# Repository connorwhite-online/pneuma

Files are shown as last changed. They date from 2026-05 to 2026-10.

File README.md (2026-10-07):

# Pneuma

**A standalone, screenless AI device with sight and sound — no phone, no app, no
memory of you except what it chooses to keep.**

Pneuma is firmware (and hardware) for a small wearable you can talk with, and —
*only when you ask* — let it see what you see. It carries its own cellular
connection, so it works on its own out in the world. You bring your own model (an
API key for a frontier provider). It is **ephemeral**: it stores no conversations,
no audio, no photos — nothing but one small, curated **memory file**.

> *Pneuma* (πνεῦμα) is Greek for **breath / spirit**. Each interaction is breath —
> it happens, then it's gone. The single memory file is the spirit that endures.

> Status: **early design / pre-implementation.** Architecture and research live
> in `docs/`; session firmware is a laptop-runnable scaffold, not device
> bring-up. Start with [`docs/ARCHITECTURE.md`](docs/ARCHITECTURE.md), then
> [`docs/RESEARCH.md`](docs/RESEARCH.md). An independent feasibility review of
> the standalone cellular spec is [`docs/FEASIBILITY.md`](docs/FEASIBILITY.md).

## What Pneuma is (and isn't)

- **Voice-first, screenless.** You speak; it speaks back. Wake word + button +
  haptics + audio cues — never a display.
- **Standalone.** Onboard **cellular (LTE Cat-1 bis)** — no phone, no companion
  app. Setup is a one-time web page the device hosts itself.
- **Vision on demand, not always-watching.** The camera powers on to grab a single
  frame *when you ask something visual*, then powers off. The opposite of the
  always-recording pendants that drew privacy backlash.
- **Bring your own LLM.** The brain is pluggable — OpenAI, Gemini, Grok, Claude.
  Your key is stored on the device, set once at setup.
- **Ephemeral + one memory file.** No history, no recordings. The only persistent
  state is a bounded (~KB), model-curated, user-resettable, portable memory file.

## How it works (one picture)

```
   ┌───────────────── PNEUMA DEVICE ──────────────────┐
   │  ┌───────────────┐   wake/power   ┌────────────┐  │   cellular (Cat-1 bis)
   │  │  WAKE ISLAND  │ ─────────────▶ │  SESSION   │  │  ──────────────────────▶  ┌──────────┐
   │  │  (always on,  │                │   BRAIN    │  │   audio + on-demand JPEG  │ PROVIDER │
   │  │   µA–mA)      │ ◀───────────── │ (Linux SoC │  │  ◀──────────────────────  │ your key │
   │  │ wake word/btn │   done/sleep   │ +modem+cam)│  │      audio reply          └──────────┘
   │  └───────────────┘                └─────┬──────┘  │
   │                              ┌──────────┴───────┐ │
   │                              │  memory file ~KB │ │  ← only persistent state
   │                              └──────────────────┘ │
   └───────────────────────────────────────────────────┘
```

A tiny always-on chip listens for the wake word; it powers up the Linux SoC +
cellular modem **only on demand** to answer, then shuts them off. That on-demand
burst (not continuous streaming) is what keeps it cool and the battery alive — the
thing the Humane Ai Pin got wrong. See [`docs/ARCHITECTURE.md`](docs/ARCHITECTURE.md).

## Repository layout

```
pneuma/
├── README.md
├── docs/
│   ├── ARCHITECTURE.md  ← system design, provider abstraction, ADRs
│   ├── FEASIBILITY.md   ← is the standalone spec actually buildable as v1?
│   ├── ENCLOSURE.md     ← aluminum body / thermal / waterproof / RF co-design
│   ├── MEMORY.md        ← the memory-file spec (the "spirit")
│   ├── PROVISIONING.md  ← one-time, app-less device setup
│   ├── PROTOCOL.md      ← internal wake-island ↔ Linux-SoC interface
│   └── RESEARCH.md       ← sourced research the design is built on
├── hardware/
│   └── BOM.md           ← bill of materials + interconnect map
└── firmware/            ← (planned) wake-island MCU + Linux session software
```

## Hardware core

A tiny always-on **wake-island MCU** (nRF52840 / Syntiant) + an on-demand **Linux
SoC** (Rockchip RV1106-class) + a **Quectel EG915U** LTE Cat-1 bis modem + a MIPI
camera, micro-speaker, mic, haptics, LED, and a ~500–1000 mAh LiPo. The
**aluminum unibody doubles as the heat exchanger** (the hot parts strap to it,
iPhone-17-Pro-style), it's **waterproof (IP68)** via a printed silicone gasket +
acoustic membranes + portless charging, and the cellular antenna sits behind a
non-metal RF window. Realistically small-puck / Ai-Pin-class — engineered to dodge
what killed the Ai Pin. Mechanical co-design: [`docs/ENCLOSURE.md`](docs/ENCLOSURE.md);
full BOM: [`hardware/BOM.md`](hardware/BOM.md); rationale in ADR-0001/0006/0007.

## License

[MIT](LICENSE) — fully open. Build it, fork it, sell it; just keep the notice.

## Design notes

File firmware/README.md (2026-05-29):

# Pneuma firmware

Two programs, matching the two-tier brain (see [../docs/ARCHITECTURE.md](../docs/ARCHITECTURE.md)).

## `session/` — the session brain (Rust, Linux SoC)

The on-demand brain: the **provider router** (Tier-1 realtime / Tier-2 composed),
the **interaction state machine** (Sleep → Connect → Capture → Converse → Forget),
and the bounded **memory file**. Hardware (modem, audio, camera, wake-island link)
sits behind traits in `session/src/hal`, with mock implementations so the whole
loop **builds and runs on your laptop today** — no hardware, no network, no keys.

```sh
cargo run  --manifest-path session/Cargo.toml    # run the mock interaction loop
cargo test --manifest-path session/Cargo.toml    # memory-file tests
```

Dependency-free for now (std only). Real drivers — an async runtime, a
WebSocket/WebRTC client to the provider, TLS, and vendor audio/camera libs — plug
in behind the existing traits. The OpenAI realtime driver stub (with the
implementation plan) is in `session/src/provider/openai.rs`.

Layout:
| Path | Job |
|---|-----|
| `src/state.rs` | the multi-turn interaction state machine |
| `src/provider/` | `Provider`/`Session` traits, `build()` router, Tier-1 (`mock`, `openai` stub) + Tier-2 `composed` (STT→LLM→TTS) |
| `src/hal/` | hardware traits (`AudioIn`+VAD, `Camera`, `Modem`, …) + mocks |
| `src/memory.rs` | the bounded memory file (load/save/compact + tests) |
| `src/tool.rs` | tool calling (MCP-style): `Tool` trait + registry + round-trip |
| `src/secure.rs` | `KeyStore` — resolves the API key from secure storage |
| `src/config.rs` | device config (provider/model/key handle) |

`provider::build(&config, &keystore)` is the router: it maps the provisioned
provider id to a Tier-1 or Tier-2 driver and pulls the key from the keystore. Both
tiers run on the laptop via mocks (`cargo run` shows a realtime conversation and a
composed query back to back).

## `wake-island/` — always-on co-processor (C, nRF52840 / nRF Connect SDK)

Wake-word + button, and power control of the session SoC. Builds against the
Nordic nRF Connect SDK (Zephyr) — not part of this repo's tooling. Scaffold only.

The interface between the two programs is specified in
[../docs/PROTOCOL.md](../docs/PROTOCOL.md).

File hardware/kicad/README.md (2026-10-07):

# Pneuma Rev A: KiCad projects (generated)

| Project | Board |
|---|---|
| `pneuma-main/` | PNM-MAIN: Luckfox Core1106-1408, nRF52840 (MDBT50Q), mics, MAX98357A, DRV2605L, camera FPC |
| `pneuma-pwr/`  | PNM-PWR: USB-C, BQ24074, LC709203F, EG800Q-NA, nano-SIM, FSUSB42, TXB0104 ×2, AT42QT1011 |

**Everything is generated from [`tools/design.py`](tools/design.py).** Edit the design there, then run
`tools/build.sh` (KiCad 10; `CQ_PY` must point to a Python with `cadquery shapely matplotlib` for the 3D check).
If you hand-edit the `.kicad_sch` or `.kicad_pcb` files, the next regeneration overwrites those edits. The exception is
**routing**: once routing starts in the KiCad GUI, stop running `gen_pcb.py` and use *Update PCB from Schematic*.
Footprint paths are set to the schematic symbol UUIDs to make that work.

- `lib/`: project symbols/footprints (Core1106 with carrier cutout, EG800Q-NA LGA-109 from the Quectel V1.1 drawings,
  RGB LED, pads) + 3D bodies
- `vendor/luckfox-core1106/`: Luckfox's KiCad symbol/footprint/STEP, pinout and schematic, unmodified
- `out/`: build output, **regenerated, mostly not versioned**. `build.sh` writes the board STEPs, schematic PDFs,
  ERC/DRC reports and the spreader DXF here; git keeps only the small readable ones (BOM CSVs, `layout-L.png`,
  `interference-L.json`). The STEP deliverables also go to the Desktop handoff folder.

Regeneration is deterministic in what matters: identical part placement, nets and coordinates every run
(`design.REV_DATE` freezes the title-block date; override with `PNEUMA_REV_DATE`). KiCad still assigns fresh
internal UUIDs and writes footprints in its own order, so the files are not byte-identical between runs.

Status: schematics pass ERC (0 errors); PCBs are placed with DRC 0 violations; **unrouted**. See [`../REV-A.md`](../REV-A.md).

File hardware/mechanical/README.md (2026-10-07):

# Enclosure K / electronics interface

Status: mechanical prototype, 2026-09-17. No fabricated or electrically validated custom PCB exists in this repo. `enclosure-k-interface.json` records CAD datums and provisional envelopes, not verified component footprints. Dimensions are millimeters. A blank mounting-hole field means undecided, not zero holes.

The current enclosure has two perimeter frames and two soft membranes. The rear rim is flush with its frame; the center recesses 0.65 mm. The internal upper spaces are opened up, and the USB wiring route connects to the main cavity. This supersedes the **mechanical concept** of a solid aluminum plateau/unibody described in older notes, but does not replace the outstanding thermal/RF analysis.

## Mounts we can establish now

Use frame-referenced rigid support for the main electronics and camera; use the TPU for cushioning and sealing. Avoid fastening alignment-critical optics into flexible membrane alone. The camera axis is 30 degrees toward the top. An angled mechanical carrier can hold the existing camera module and its FFC; an angled custom camera PCB is not required solely to set that angle.

Keep the newly opened upper volume available for a camera carrier, possible mic/LED board, speaker and cabling. It is not all free PCB area: speaker acoustics, camera lens projection, FFC bends, frame catches, antenna and thermal keepouts consume space. Final board shapes must be checked as populated assemblies, not bare rectangles.

Do not yet cut final screw bosses or hole patterns. Confirm board variants/outlines, height, mounting holes, connector entry and tool access first. An adjustable/removable carrier is preferable for early fit experiments. Choose screw size and boss geometry after measuring available wall and installation clearances.

## Board partition proposed for review

1. Main compute/power board or initial module carrier, referenced to the frame. Do not freeze a bare-RV1106 design before integration bring-up.
2. Camera module on an angled rigid carrier, native MIPI FFC back to compute.
3. Optional small mic/LED daughterboard near their ports. The IM69D130 is bottom-port: the PCB and seal need an aligned acoustic path. Do not connect two PDM clock drivers together; decide microphone ownership/routing explicitly.
4. Speaker held separately in a retained, sealed acoustic seat, with a removable wire connection. The 18 mm BOM speaker does not imply an 18 mm exterior opening, and the existing small outlet row has not been acoustically validated.
5. USB-C board/connector positively retained against cable insertion load, with the open interior wiring route. Choose the exact connector and power/data routing before mounting holes.
6. Touch electrode behind the thin touch area. Controller, electrode shape, ground keepout and sensitivity are not yet specified in the BOM.

The four enclosure pieces remain four pieces. Additional rigid electronic carriers, if selected, are internal assembly parts and need their own drawings.

## Decisions before schematic/placement freeze

- Existing development boards and intended cellular region/carrier. The BOM itself flags EG915U-EU as unsuitable for the proposed US use.
- Exact SC3336 module drawing and connector pin count/pinout; vendor module identity alone is insufficient for a footprint.
- Confirm whether two-way earbud microphone support is required. The repo's BM83 Tx-mode notes do not establish HFP Audio Gateway support.
- USB-C variant, input power requirement, charging/current budget, battery protection and temperature sensing. Do not treat the current mouth cutout as a verified connector fit.
- Antenna layout and thermal path for a perimeter-metal/soft-face enclosure. The old unibody heat-spreader assumption no longer applies.
- Main board thickness, stackup, connector heights and practical service/removal order.

## KiCad workflow

Create schematic sheets for power, wake/touch, compute, cellular, audio and interconnect only after sourcing the corresponding manufacturer reference designs and pinouts. Link each symbol/footprint to a checked part variant. Keep unknown values explicitly unresolved; do not substitute convenient footprints.

Export populated board STEP models from KiCad into enclosure coordinates. Check component bodies, solder joints, underside parts, connector mating and removal space, cable bends and screw access. Only then transfer actual board-hole coordinates into CAD and export new meshes.

Run ERC and DRC with a documented fab stackup, impedance constraints and reviewed exceptions. Passing these checks is not electrical validation. Bench-test power rails/current limiting, wake latency, audio, camera, modem bursts and thermal behavior before a fully integrated board spin. Fabrication outputs should be released only after the pending decisions and reviews are resolved.

## First bench milestones

Record exact board/firmware variants and wiring, then bring up each power domain separately on a suitable current-limited supply. Prove camera capture and audio locally, then add modem connectivity and the realtime workload. Measure peak current, wake-to-first-audio and sustained temperatures. Fit inert board/component dummies into the enclosure before installing a live battery. Log measured results and failures in the repo; no bench measurements have been performed as part of K.

For PLA enclosure fit, start with the latch coupon. The new geometry is a test iteration, not an SLM spring design or seal qualification.

## Manufacturer references checked during this update

- [Waveshare SC3336 Camera B](https://www.waveshare.com/wiki/SC3336_3MP_Camera_%28B%29): the B version changes the copper-plated fixing-hole provision. Confirm actual mechanical retention on the purchased module rather than assuming the A variant mounting details.
- [Infineon IM69D130 datasheet](https://www.infineon.com/assets/row/public/documents/24/49/infineon-im69d130-datasheet-en.pdf): package and acoustic-port guidance; use the manufacturer land pattern in the PCB design.
- [Microchip BM83 features](https://onlinedocs.microchip.com/oxy/GUID-414904F5-364E-4377-B959-9226AD29D6A9-en-US-8/GUID-90AB7782-7237-42CB-802D-B4DB2B9C5608.html): AT mode lists A2DP source or A2DP/HFP sink. That does not establish the HFP Audio Gateway role needed for an earbud microphone.
- [KiCad CLI documentation](https://docs.kicad.org/9.0/en/cli/cli.html): PCB STEP/GLB export for enclosure integration. Use documentation matching the installed version. KiCad was not installed on the workstation at this update; no ERC/DRC or native KiCad file validation has been run.

## Enclosure L (next): electronics interface for Rev A

Rev A boards are placed, and the enclosure grows **+10 mm** (a straight insert at y = −10; the camera end is unchanged).
[`enclosure-L-electronics.json`](enclosure-L-electronics.json) carries everything in these axes:
- board outlines, z-levels and M1.6 hole positions
- every part courtyard and side
- mic ports, LED, the USB-C mouth (z 6.46) and service access
- off-board envelopes: battery, FFC, speaker, LRA, camera

Requirements are listed in [`../REV-A.md`](../REV-A.md) §6. Populated STEPs come from `hardware/kicad/tools/build.sh`.

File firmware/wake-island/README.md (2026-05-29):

# Pneuma wake island (nRF52840)

Always-on co-processor firmware: wake-word + button detection and power control
of the Linux session SoC. C, on the **Nordic nRF Connect SDK (Zephyr)**.

```
west build -b nrf52840dk/nrf52840 firmware/wake-island
west flash
```
(Requires the nRF Connect SDK toolchain — not part of this repo's CI.)

## Layout
| File | Job |
|---|-----|
| `src/main.c` | the wake → power-up → hand-off → power-down loop |
| `src/wakeword.c` | always-on KWS on the PDM mic (TFLM/CMSIS-NN or Syntiant) |
| `src/button.c` | button gesture classification |
| `src/power.c` | `SOC_EN` control of the session tier |
| `src/uart_link.c` | control protocol to the SoC (see ../../docs/PROTOCOL.md) |

Status: **scaffold** — module bodies are TODO stubs.

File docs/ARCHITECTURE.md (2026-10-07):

# Pneuma — Architecture

Pneuma is a **standalone, screenless, voice-first AI device** with on-demand
vision and a pluggable ("bring your own") model. It carries its own cellular
connection — **no phone, no companion app** — and is **ephemeral**: it stores
nothing except one small, curated memory file.

This document is the synthesis of the research in [`RESEARCH.md`](RESEARCH.md).
Genuine forks are captured as **Architecture Decision Records (ADRs)** at the end.

Status: **design, pre-implementation.** This is the blueprint, built for the
*right* core rather than a throwaway prototype. An independent review of whether
this spec is a feasible *v1* (vs. a desk demo vs. a consumer product) is
[`FEASIBILITY.md`](FEASIBILITY.md).

> **Name & principle.** *Pneuma* (πνεῦμα) = breath / spirit. Each interaction is
> breath — it happens and is gone. The one persistent memory file is the spirit
> that endures. The device is otherwise stateless.

---

## 1. System overview

There is no phone in the loop. Three tiers, all on or beyond the device itself:

| Tier | What it is | Job | Power |
|---|---|-----|---|
| **Wake island** | Tiny always-on MCU (nRF52840 / Syntiant) | Wake word, button, sensors; powers the session tier up/down | µA–mA, always on |
| **Session brain** | Small Linux SoC (Rockchip RV1106-class) + **Cat-1 bis modem** + camera | Provider router, realtime session over cellular, on-demand photo, audio I/O | watts, **on-demand only** |
| **Provider (brain)** | User's chosen cloud model | Reasoning + (Tier 1) speech | remote, user's API key |

```
   ┌───────────────── PNEUMA DEVICE ──────────────────┐
   │                                                   │
   │  ┌───────────────┐   wake/power   ┌────────────┐  │      cellular (Cat-1 bis)
   │  │  WAKE ISLAND  │ ─────────────▶ │  SESSION   │  │  ─────────────────────────▶  ┌──────────┐
   │  │  (always on)  │                │   BRAIN    │  │     LC3/Opus audio + JPEG     │ PROVIDER │
   │  │ • wake word   │ ◀───────────── │ (Linux SoC │  │  ◀─────────────────────────   │ (your    │
   │  │ • button      │   done/sleep   │  + modem   │  │       audio reply             │  API key)│
   │  │ • mic monitor │                │  + camera) │  │                               └──────────┘
   │  └───────────────┘                └─────┬──────┘  │
   │                                         │         │
   │                              ┌──────────┴───────┐ │
   │                              │  memory file     │ │  ← the only persistent state
   │                              │  (bounded, ~KB)  │ │
   │                              └──────────────────┘ │
   └───────────────────────────────────────────────────┘
```

**Why a Linux SoC, not an MCU:** standalone realtime voice over cellular needs a
real WebRTC/TLS stack, hardware JPEG, OTA, and robust connection management.
Every shipping standalone-cellular voice device works this way (the Humane Ai Pin
used a phone-class Snapdragon). See ADR-0001.

**Why the wake island exists:** the Linux SoC + modem are power- and heat-hungry,
so they must be *off* almost always. A tiny always-on MCU listens for the wake
word and only powers the session tier up to answer, then cuts it. This on-demand
duty cycle is what keeps the device cool and the battery alive (see §6).

---

## 2. The interaction loop

```
   ┌──────────────────────────────────────────────────────────────────────┐
   │  SLEEP — session brain powered OFF; wake island listening (µA–mA)      │
   └───────────────┬────────────────────────────────────────────────────────┘
                   │ "Hey Pneuma"  (or button)  → wake island powers up brain
                   ▼
   ┌──────────────────────────────────────────────────────────────────────┐
   │  CONNECT — Linux SoC boots/resumes, modem attaches, loads memory file  │
   │  earcon (rising chime) + LED + haptic tap                              │
   └───────────────┬────────────────────────────────────────────────────────┘
                   │  (intent appears visual? "what am I looking at?")
                   ▼
   ┌──────────────────────────────────────────────────────────────────────┐
   │  CAPTURE (on-demand only) — power camera, grab ONE JPEG, then off      │
   │  visible/audible capture indicator                                     │
   └───────────────┬────────────────────────────────────────────────────────┘
                   ▼
   ┌──────────────────────────────────────────────────────────────────────┐
   │  CONVERSE — stream audio (+frame) to chosen provider over cellular;    │
   │  play voice reply; (optionally) update the memory file                 │
   └───────────────┬────────────────────────────────────────────────────────┘
                   │  silence / "thanks" / timeout
                   ▼
   ┌──────────────────────────────────────────────────────────────────────┐
   │  FORGET & SLEEP — drop all audio/frames/context, power modem + SoC     │
   │  down, return to wake island. Nothing kept but the memory file.        │
   └────────────────────────────────────────────────────────────────────────┘
```

The expensive tier lives only inside CONNECT→CONVERSE; the rest of the time the
device is asleep but listening. Camera is powered only inside CAPTURE.

---

## 3. The provider abstraction (the core of "bring your own LLM")

This runs **on the device** (in the Linux session brain), not in any app.
Providers expose their "brain" two ways; Pneuma implements both behind one
interface.

### Tier 1 — `RealtimeProvider` (native speech-to-speech)
One streaming socket: audio (and sometimes video) up, voice down. Lowest latency,
least local compute — ideal over cellular.
- **OpenAI** `gpt-realtime` — audio + image, WebRTC/WS.
- **Google Gemini Live** — audio + **native video (~1 fps)**, WebSocket.
- **xAI Grok Voice** — audio, WebSocket, **OpenAI-Realtime-compatible** (one driver → two providers).
- **AWS Nova Sonic** — audio, HTTP/2.

### Tier 2 — `ComposedProvider` (STT → text LLM → TTS)
Device orchestrates the pipeline (calling cloud STT/TTS APIs). **Required** for:
- **Anthropic Claude** — text/vision only, no native S2S.
- (Future) on-device/off-grid models, if the Linux SoC's NPU is ever used for a local fallback.

### Interface (illustrative)
```
Provider.startSession(opts) -> Session
Session:
  pushAudio(chunk)      // mic up
  pushImage(jpeg)       // on-demand frame up
  audioReply -> stream  // voice down
  transcript -> stream  // text, for memory updates / tools
  toolCalls  -> stream  // MCP
  endTurn(); close()
```
Adding a model = adding one driver + a stored key. The memory file is injected
into the session as context at start (see §5).

### Capability matrix
| Provider | Native voice | Vision | Auth |
|---|---|---|---|
| OpenAI `gpt-realtime` | ✅ | image | key + ephemeral token |
| Gemini Live | ✅ | ✅ video ~1fps | key + ephemeral token |
| xAI Grok | ✅ (OpenAI-compatible) | audio | key |
| AWS Nova Sonic | ✅ | audio | SigV4 |
| Anthropic Claude | ❌ → Tier 2 | image | key |

Glue: **MCP** for tools/routing. Keys are stored on-device (secure element /
encrypted flash), set once during provisioning (see [`PROVISIONING.md`](PROVISIONING.md)).

---

## 4. Hardware core

| Function | Part (indicative) | Notes |
|---|---|---|
| **Wake island** | Nordic **nRF52840** (or Syntiant **NDP120** for <1 mW KWS + beamforming) | always-on KWS (DS-CNN/TFLM), button, BLE for setup, powers the SoC |
| **Session SoC** | Rockchip **RV1106** (Cortex-A7 + ISP + ~0.5–1 TOPS NPU, tiny) | Linux; native MIPI camera ISP + HW JPEG; runs the provider router |
| **Cellular** | Quectel **EG915U** (LTE **Cat-1 bis**, single antenna, ~24×20×2.4 mm) | full-duplex, <100 ms; data-only (voice-over-data) |
| **Camera** | small MIPI-CSI sensor (via RV1106 ISP) | on-demand single JPEG; powered off otherwise |
| **Mic** | Infineon **IM69D130** (PDM) | monitored by wake island for KWS; routed to SoC in session |
| **Audio out** | **MAX98357A** (I2S) + 20 mm 8 Ω speaker; **+ Bluetooth A2DP** to earbuds | speaker fires toward face; earbuds = private/clear (ADR-0008) |
| **Haptics** | LRA + **DRV2605L** | state cues without a screen |
| **Indicator** | RGB LED | + earcons |
| **SIM** | **SGP.32 eSIM** or on-die **iSIM** | remote-provisionable, no UI needed |
| **Power** | LiPo ~500–1000 mAh + power-path PMIC + 100–470 µF bulk cap | LTE = steady ~0.8 A draw (no 2G spikes), so no supercap needed |
| **Thermal** | graphite/Cu heat spreader; outward radiating face; skin-side insulation | passive only (see §6) |
| **Storage** | SoC SPI-NAND/eMMC | holds OS + the memory file |

Full BOM + interconnect: [`../hardware/BOM.md`](../hardware/BOM.md).
Internal wake-island ↔ SoC interface: [`PROTOCOL.md`](PROTOCOL.md).

---

## 5. Ephemerality & the memory file

**Ephemeral by default.** No transcripts, no audio, no photos are retained. A
session's audio and any captured frame are streamed to the provider and dropped.
Nothing about *what you said or saw* persists.

**The memory file — the only persistent state.** A single bounded file (target a
few KB, hard cap) the model curates:
- **Content:** durable facts about the user (name, preferences, a handful of
  standing instructions) — *not* a conversation log.
- **Lifecycle:** read into the session as context at CONNECT; the model may
  propose updates during CONVERSE; on FORGET the device keeps only the updated
  memory file and discards everything else.
- **Bounded:** when near the cap, the model must *summarize/compress* rather than
  append — a rolling memory, so it never grows into a log.
- **On-device only:** never uploaded except as context to the user's *own* chosen
  model during a session. Stored in encrypted flash.
- **User-controlled:** viewable/editable during provisioning; **factory reset =
  forget me**; ideally **portable** (export/import to move your "self" to another
  Pneuma).

See ADR-0005.

---

## 6. Thermal & power (the make-or-break)

The Humane Ai Pin proved standalone-cellular AI is **thermally** hard: continuous
LTE streaming (~3 W modem) + an always-on app SoC is 2–6 W in a sealed body, which
throttled it. Skin-facing surfaces must stay **≤43 °C** (target ≤40–42 °C).

Pneuma's strategy is to *not generate the heat continuously*:
- **On-demand duty cycle** — the modem + SoC are off except during a session; the
  device bursts and sleeps, the regime that lets Apple Watch LTE and kids' GPS
  watches stay cool. (This is why the wake island exists.)
- **Aluminum body as the heat exchanger** (cf. iPhone 17 Pro): strap the two heat
  sources — the **modem PA** and the **SoC** — through TIM + graphite into the
  **aluminum unibody**, which radiates. On-demand bursts dump little energy into a
  large metal mass, so temperature barely rises. An *active* heat exchanger is
  **not feasible** at this scale (a few cm² shed only ~0.1–0.3 W/°C; no room/power
  for fans/pumps) — the body *is* the spreader. Radiate from the outward face;
  insulate the skin side (metal must stay ≤43 °C against skin).
- **Power** — LTE draws a steady ~0.7–0.8 A while connected (no 2 G micro-spikes),
  so a single LiPo + bulk cap + power-path PMIC suffices. Runtime ≈ hours of
  active talk; all-day on the on-demand model.

The aluminum body, the waterproof seal, and the antenna all interact (a metal body
is a Faraday cage, so the antenna needs a non-metal RF window) — designed together
in [`ENCLOSURE.md`](ENCLOSURE.md). See ADR-0006 and ADR-0007.

---

## 7. Privacy & trust posture

- **Standalone, no app, no Pneuma server.** Audio/photos go only to *your* chosen
  provider, over your own SIM.
- **Ephemeral.** Nothing to leak — no history, no recordings; only the small,
  on-device, user-resettable memory file.
- **On-demand capture** — camera powered only during an indicated CAPTURE; no
  ambient recording. This is the differentiator the always-on incumbents
  (Friend, Bee, Limitless) structurally lack.
- **Open + self-hostable-ish** — fully open firmware; the only cloud dependency is
  the model *you* chose and pay for.

---

## 8. Capabilities & power modes

Beyond conversation, the device's abilities are **tools** (§3, MCP-style) the model
invokes — adding a capability = adding a tool + any hardware it needs (real builds
register a tool only when its hardware/config is present). Each capability implies a
**power mode**:

| Mode | What | Power | Notes |
|---|---|---|---|
| Sleep / listen | wake-island only | µA–mA | always |
| On-demand Q&A | wake → cloud realtime burst → sleep | ~3 W, ~30–60 s | the core loop |
| Navigation | fetch route once → wake-island tracks GPS → SoC wakes per turn | ~0.3–0.7 W, sustained | needs a GNSS-capable modem + GNSS antenna; ~10–20 h |
| Media (Spotify/BT) | librespot stream → Bluetooth audio out | ~0.5–1 W, sustained | Premium; ~1 MB/min cellular data — prefer Wi-Fi; needs a BT-Classic/A2DP path |

- **Location/directions** — `get_location` + `directions` tools. On-demand ("how do
  I get to X?") is on-grain; live turn-by-turn is cheap *because the route is cached
  and tracking runs on the wake-island*, with the SoC waking only per turn.
- **Bluetooth audio out** (ADR-0008) — pairs AirPods/BT headphones for private,
  clear AI voice + music. A2DP source is mature on Linux (BlueZ); the requirement is
  a SoC/module with **BT-Classic/A2DP** support (the RV1106 IPC BSP is BLE-leaning),
  else a dedicated A2DP-source chip. Routed via a second `AudioOut` HAL impl.
- **Music over cellular is data-heavy** (~60 MB/h vs voice's ~20 MB/h) — fine on
  Wi-Fi, real money on a metered IoT SIM.
- **Projection (optional / experimental)** — this form factor *can* do on-demand,
  **glanceable 2D** projection (palm/surface) via a DLP Pico or laser-scanning engine
  behind a sealed optical window. The on-demand duty cycle keeps heat/battery in
  budget for brief (5–10 s) flashes — those walls only bite *sustained* bright use.
  Real limits: **daylight readability** (optics, not heat) and **packaging volume** vs.
  the battery. **Free-space 3D / holograms are not feasible** at any scale. Off the
  screenless thesis — a deliberate scope/cost tradeoff, not a default (Ai Pin proved
  it fits; its failure was UX, not feasibility).

---

## Architecture Decision Records

> **Decision history.** Earlier drafts assumed a phone-tethered, credential-free
> pendant (first on a single ESP32-S3, then a single nRF5340). Both were
> superseded when the **standalone, no-phone** requirement surfaced: with no phone
> to provide internet or hold keys, the device must carry cellular + a real SoC
> itself. The ADRs below reflect the standalone design.

### ADR-0001 — Standalone cellular on a small Linux SoC + always-on wake island

**Status:** Accepted. (Supersedes the phone-tethered ESP32-S3 and nRF5340 cores.)

**Decision.** Build a standalone device: a tiny **always-on MCU** (wake word +
power control) that boots a small **Linux SoC** (Rockchip RV1106-class) + a
**Cat-1 bis modem** (Quectel EG915U) + camera **on demand** for each session.

**Rationale.** No phone → the device needs its own internet radio and its own
compute. Realtime voice over cellular requires a Linux-class WebRTC/TLS/OTA stack
(unproven on bare MCUs; the Ai Pin used a Snapdragon). Cat-1 bis is the right
cellular tier (full-duplex, <100 ms, single antenna); LTE-M is too jittery for
live voice. The wake island keeps the power/heat-hungry tier off ~99% of the time.

**Consequences.** This is a tiny wearable Linux computer (Ai-Pin-class), not a
cheap flashable MCU — higher cost/complexity, accepted deliberately. Thermal is
the binding constraint (ADR-0006). Runtime is hours-of-talk / all-day-on-demand.

### ADR-0002 — Two-tier provider abstraction, device-resident

**Status:** Accepted (revised: now runs on the device, not a phone app).

The `RealtimeProvider` / `ComposedProvider` split (see §3) lives in the Linux
brain. It is the only way "bring your own LLM" covers both native-voice providers
and Claude/local. Keys are stored on-device, set once at provisioning.

### ADR-0003 — Audio output is a micro-speaker, not bone conduction

**Status:** Accepted. Bone conduction needs skull contact a pendant can't provide
(collarbone is its worst location); a micro-speaker is the only reliably
intelligible option. Caveat: weak outdoors, not private; optional BT-earbud
fallback.

### ADR-0004 — No companion app; one-time on-device web provisioning

**Status:** Accepted. (Replaces the earlier Flutter-app decision.)

There is no phone app. First-run configuration (API key, model choice, eSIM
profile, memory seed) is served by a web page the **device itself** hosts over a
temporary setup link (BLE/Wi-Fi SoftAP/USB), reachable from any browser, then
disabled. See [`PROVISIONING.md`](PROVISIONING.md).

### ADR-0005 — Ephemeral device with a single bounded memory file

**Status:** Accepted.

The device retains **no** conversation/audio/photo history. The only persistent
state is one bounded (~KB), model-curated, on-device, user-resettable, portable
memory file (see §5). This is the privacy foundation and the product's identity
(*pneuma* = breath vs. spirit).

### ADR-0006 — Thermal: passive spreading + on-demand duty-cycling, no active cooling

**Status:** Accepted.

An active heat exchanger isn't feasible at pendant scale. The device stays within
the ≤43 °C skin limit by **not generating heat continuously** (on-demand bursts,
via the wake island) plus **passive graphite/Cu spreading** to an outward
radiating face with skin-side insulation. Continuous streaming — the regime that
throttled the Ai Pin — is explicitly avoided.

### ADR-0007 — Aluminum unibody as heat spreader; sealed-USB-C waterproof; non-metal RF window

**Status:** Accepted.

**Decision.** Use an **aluminum unibody** as both structure and heat exchanger
(hot parts strapped to it via TIM + graphite); make the device **waterproof
(target IP68)** with a printed silicone gasket, acoustic membranes for mic/speaker,
and **sealed USB-C** charging+data (IP67 receptacle, gasket-wrapped); and place the
cellular antenna behind a **non-conductive RF window** in the body, isolated from
the metal.

**Rationale.** A metal body is the best passive spreader *and* a Faraday cage, so
the antenna must get a deliberate non-metal window; the outward face is contended
between radiator and antenna and is resolved in 3D (radiator + sides aluminum; RF
window at an edge, away from the body). USB-C is kept for data (flashing / dev /
recovery) and sealed IP67-style — the one waterproofing weak point, solved with a
gasketed receptacle.

**Consequences.** Bigger than a tiny pendant (small-puck/Ai-Pin class); the
enclosure becomes a real co-design of thermal + RF + sealing. Detailed in
[`ENCLOSURE.md`](ENCLOSURE.md).

### ADR-0008 — Bluetooth audio output (A2DP) is first-class

**Status:** Accepted.

**Decision.** Private, clear audio out via **Bluetooth A2DP** to earbuds/headphones
(AirPods or any BT sink) is **table-stakes**, alongside the speaker. Treat **BlueZ
A2DP-*source* support as a hard requirement** when selecting the production SoC /
Wi-Fi-BT module (Path A, ~$0 extra); fall back to a **dedicated A2DP-source BT-audio
chip fed by I2S** (Path B, ~$5–8) if the chosen SoC's BT stack can't. Adds a 2.4 GHz
BT antenna + a pairing flow; output routes through a second `AudioOut` HAL impl
(speaker vs BT, BT-when-connected).

**Rationale.** A bare micro-speaker is weak and non-private outdoors (ADR-0003);
earbuds make the assistant usable in public and double for music/calls. A2DP source
is mature on Linux (BlueZ) — the only real risk is the RV1106 IPC BSP being
BLE-leaning, hence the selection requirement. Optional **HFP** adds the earbud mic
for fully discreet two-way.

**Consequences.** Constrains the SoC/module choice (or adds a chip); ~100–200 ms
A2DP latency stacks on the cloud round-trip (use AAC for AirPods quality). Elevates
the BT-earbud "optional fallback" of ADR-0003 to a first-class output. **Resolved by
ADR-0009: Path B (dedicated BM83 chip).**

### ADR-0009 — SoC is RV1106 (G3) + a dedicated BM83 Bluetooth-audio chip

**Status:** Accepted. (Deep SoC pass — see [`RESEARCH.md`](RESEARCH.md) §8.)

**Decision.** Keep the **Rockchip RV1106 G3 (256 MB)** as the session SoC and add a
**Microchip BM83** (A2DP-*source* "AT" firmware, I²S + UART, ~$12) to own Bluetooth
audio. Do **not** step up to a larger SoC for Bluetooth's sake.

**Rationale.** The RV1106 already clears the two hard requirements that matter for
size: realtime audio (a single A7 + offloaded camera ISP/VPU is enough for Opus-over-
WebSocket) and the MIPI camera. Its *only* real gap is A2DP — its BlueZ stack is
broken/BLE-flavored — and a dedicated BM83 fixes that completely and cheaply, also
giving HFP (earbud mic) and hardware AAC (better AirPods quality than the Linux
libfdk-aac path). This honors the smallest/lowest-power priority while de-risking the
weak spot.

**Alternatives.** **RK3566** (quad-A55) is the documented one-chip fallback — mature
BlueZ A2DP + ISP + headroom, but ~1.2 W idle and bigger. **Qualcomm QCM2290** is the
"funded scale-up" ideal (dual ISP + **integrated LTE modem** + first-class Linux), but
production is NDA/SoM-gated. Disqualified: RK3308 (no usable camera), i.MX 8M Mini/7,
AM62x, STM32MP1, Allwinner T113 (missing ISP/encoder/MIPI).

**Consequences.** Several radios on the board (cellular + Wi-Fi/BLE + BM83 BT-audio +
GNSS) → 2.4 GHz antenna coordination is a real layout task. A 1-day hardware spike to
confirm A2DP-to-earbuds is still prudent, though the BM83 largely moots the risk.

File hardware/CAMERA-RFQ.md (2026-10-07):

# Camera module RFQ — Pneuma Rev A

Send this to camera module houses (Sincere, Hampo, CK Vision, Sinoseen, or any Shenzhen module
supplier). It is written so you can paste §2–§7 straight into an email. Background and the reasoning
behind the numbers are in [`REV-A.md`](REV-A.md) §7; coordinates are in
[`mechanical/enclosure-L-electronics.json`](mechanical/enclosure-L-electronics.json).

**Why this is blocking:** the PCB is finished and does not depend on which module you pick (the FFC
connector and its pinout are frozen). The *enclosure* cannot be modeled until the module's outline,
height and FFC exit are known.

---

## 1. Shortlist to ask about first

Any sensor below already has both a kernel driver and an **ISP tuning (IQ) file** in the Luckfox
RV1106 SDK, so it works without commissioning new tuning. In rough order of preference:

| Sensor | Format | Notes |
|---|---|---|
| **GC2053** | 1/2.9", 2 MP | the sensor in most small MIPI FPC modules — most likely to exist off-the-shelf in a compact build |
| **SC3336** | 1/2.8", 3 MP | Luckfox's own tested camera; the bench module uses it |
| **SC3338**, **SC2336**, **SC230AI**, **SC200AI** | 2–3 MP | all tuned in the SDK |
| SC4336, SC401AI, SC500AI, SC530AI, MIS2032, OS02H10, GC1084 | 2–5 MP | also tuned; only if the above can't be made short enough |

Full list in the SDK at `media/isp/release_camera_engine_rkaiq_rv1106_*/isp_iqfiles/`.

**Sensors without SDK tuning are a non-starter** unless the supplier provides an RV1106 IQ file.

## 2. What we need

A **fixed-focus MIPI CSI-2 camera module on an FPC/FFC tail**, for a battery-powered wearable that
takes occasional stills (not continuous video). Host SoC is a **Rockchip RV1106G3** (Luckfox
Core1106). Quantities: **3–10 samples now**, then 50–200 for a pilot build.

## 3. Mechanical (the hard constraint)

| Item | Requirement |
|---|---|
| **Module outline** | **≤ 12 × 12 mm** board |
| **Total height** | **≤ 6.0 mm** including the lens, measured from the module PCB's underside |
| Lens barrel | must not protrude more than the 6.0 mm total; no M12 holder |
| FFC tail | exits one edge, ≥ 25 mm usable length, 0.5 mm pitch, must fold 180° |
| Mounting | 2 holes or adhesive pad face; tell us what the module offers |
| Tolerance | we need a **2D drawing (PDF or DXF) and ideally a STEP model** before ordering |

The module sits tilted **30° from vertical**, which is why the footprint matters as much as the
height: a wider board swings its corners down into the SoC below.

**If you can offer a taller or wider module, tell us the exact numbers anyway** — we can trade
enclosure bump height against module size:

| Camera bump grows by | Largest module that still fits |
|---|---|
| **0 mm (preferred)** | **12 × 12 × 6 mm** |
| 1 mm | 16 × 16 × 6 mm |
| 2 mm | 16 × 16 × 7 mm |
| 4 mm | 16 × 16 × 9 mm |

## 4. Optical

| Item | Requirement |
|---|---|
| FOV | **90–110° diagonal** (a 150° fisheye is what makes most modules tall; we don't need it) |
| Aperture | F2.0–F2.4 is fine; we do not need F1.6–F1.9 if it costs height |
| Focus | fixed focus, hyperfocal from ~30 cm to infinity. No VCM/autofocus |
| IR filter | **IR-cut fitted** (daylight/indoor use, no night vision) |
| Resolution | 2 MP minimum; 3 MP preferred. Stills, ~1–5 fps, not 30 fps video |

## 5. Electrical

| Item | Requirement |
|---|---|
| Interface | **MIPI CSI-2, 2 data lanes + clock** |
| Supply | single **3.3 V** into the module; on-board LDOs for AVDD/DOVDD/DVDD |
| Control | I²C (SCCB), plus **RESET** and an external **MCLK** input |
| MCLK | tell us the required frequency (24 MHz preferred) and whether the module has its own oscillator |
| I²C address | tell us the 7-bit address and whether it is strappable |

## 6. Connector and pinout

Our board has a **20-pin 0.5 mm FFC connector wired to the Luckfox camera pinout**:

| Pin | Signal | Pin | Signal | Pin | Signal | Pin | Signal |
|---|---|---|---|---|---|---|---|
| 1 | GND | 6 | GND | 11 | CSI_D1N | 16 | RESET |
| 2 | MCLK | 7 | CSI_CLK P | 12 | GND | 17 | GND |
| 3 | GND | 8 | CSI_CLK N | 13 | I2C SCL | 18 | GND |
| 4 | CSI_D0P | 9 | GND | 14 | I2C SDA | 19 | +3.3 V |
| 5 | CSI_D0N | 10 | CSI_D1P | 15 | GND | 20 | +3.3 V |

**A 24-pin module is equally acceptable** — send us your standard pinout and we will match the board
to it. Please state:
- pin count and pitch
- **contact side: same-side (type A) or opposite-side (type B)** on the module end
- FFC stiffener location

## 7. Questions to answer with the quote

1. Part number, and the **2D drawing + STEP** for the exact build
2. Module outline and **total height including lens** (mm)
3. Sensor, lens EFL, FOV, F-number, IR-cut yes/no
4. FFC pin count, pitch, contact side, tail length
5. MCLK requirement and I²C address
6. **Do you supply an RV1106/RK ISP tuning (IQ) file for this sensor+lens pair, or should we use the Luckfox SDK's?**
7. MOQ, unit price at 10 / 50 / 200, lead time for samples
8. Whether you can supply **one sample with a 20-pin Luckfox-pinout tail** for immediate bring-up

## 8. What we do while waiting

Bench work uses the **Waveshare/Luckfox SC3336 3MP Camera (B)** ($9), which matches J4's pinout
exactly. That proves the driver, ISP and capture path; only the mechanical fit depends on this RFQ.

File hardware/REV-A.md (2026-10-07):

# Pneuma Rev A: board and BOM freeze (bench, then enclosure L)

Status, 2026-09-19. **Frozen:** architecture, part selection, schematics, board outlines, component placement,
inter-board pinout and the enclosure interface. **Not done:** copper routing, fab outputs and any electrical
validation. The PCBs are *placed, not routed*. Nothing here has been built or powered.

| Artifact | Where |
|---|---|
| Single source of truth (every part, pin and net) | [`kicad/tools/design.py`](kicad/tools/design.py) |
| KiCad 10 projects (schematic + placed PCB) | [`kicad/pneuma-main/`](kicad/pneuma-main), [`kicad/pneuma-pwr/`](kicad/pneuma-pwr) |
| Board BOMs (grouped, with MPNs) | [`kicad/out/pneuma-main-bom.csv`](kicad/out/pneuma-main-bom.csv), [`kicad/out/pneuma-pwr-bom.csv`](kicad/out/pneuma-pwr-bom.csv) |
| Populated board STEPs (KiCad export) | `kicad/out/pneuma-main.step`, `kicad/out/pneuma-pwr.step` |
| Enclosure-L interface (all coordinates, z-levels, envelopes) | [`mechanical/enclosure-L-electronics.json`](mechanical/enclosure-L-electronics.json) |
| Layout plan + side view | [`kicad/out/layout-L.png`](kicad/out/layout-L.png) |
| Thermal estimate (why there's no spreader) | [`kicad/tools/thermal_estimate.py`](kicad/tools/thermal_estimate.py) |
| Regenerate everything | `hardware/kicad/tools/build.sh` |
| Camera module RFQ (blocking enclosure L) | [`CAMERA-RFQ.md`](CAMERA-RFQ.md) |

Checks run on the generated files with KiCad 10.0.6 `kicad-cli`:
- **ERC:** 0 errors on both boards.
- **DRC:** 0 violations apart from unrouted nets.
- **3D:** a solid-intersection check of boards, battery, FFC, speaker, LRA and camera envelopes found 0 interferences.

None of these checks is electrical validation.

---

## 1. What changed from the old BOM, and why

| Old | Rev A | Reason |
|---|---|---|
| Quectel **EG915U-EU** | **EG800Q-NA** (Cat-1 bis, B2/4/5/12/13/66, LGA-109 15.8×17.7×2.4) | EG915U-EU has no US bands. EG800Q-NA covers AT&T/Verizon LTE and T-Mobile except B71. It is stocked at JLCPCB (C41406928). |
| Bare RV1106G3 custom SoC | **Luckfox Core1106-1408** SoM (RV1106G3, 256 MB, 8 GB eMMC, WiFi6/BT5.2) | Your choice: the SoC, DDR, eMMC, PMIC and radio are Luckfox-validated, so first-spin risk drops. |
| Microchip BM83 | **Removed** (Core1106 BT5.2 for A2DP, validated on the bench first) | 32×15 mm doesn't fit. The BM83 AT firmware also has no HFP-AG role. |
| SC3336 3MP Camera (B) | **Connector/pinout frozen (Luckfox 20P); the module itself is NOT chosen** — see §7 | The (B) is 25×24 mm with a 23.95 mm M12 lens stack and can't fit even tilted. The board doesn't care which module you use; the enclosure bump does. |
| PKCell LP803860 2000 mAh | **LP702040, 500 mAh / 1.85 Wh, 7.0×20×40 mm** with PCM + wires | Volume. See §4. (The 550 mAh version of the same cell is 41 mm long and needs 1 mm more bay.) |
| PUI AS01808MR-R 18 mm speaker | **PUI AS01508MR-LWC40 class, 15 mm** | 18 mm collides with the camera over the Core. |
| USB-C GCT USB4500 (IP67) | **GCT USB4105-GF-A** | K's port isn't sealed yet. The IP67 part returns with the seal design. |
| BQ24074 on VSYS for everything | BQ24074, but **modem on VBAT** | BQ24074 OUT regulates to **4.4 V**, above the EG800Q's 4.3 V maximum (TI datasheet, device comparison table). |
| Aluminum perimeter frames + TPU membranes (K) | **Two-piece silicone/TPU shell, no metal**, plus a rigid internal carrier | A metal ring around the whole device was the biggest unsolved LTE-antenna problem. Soft skin also feels cooler at the same temperature. |
| Aluminum unibody as heat sink + graphite | **PCB copper does the spreading; two off-the-shelf silicone gap pads** carry board→shell | Measured first: a 60 s session lifts the device ~2.3 K, and the 43 °C ceiling is set by skin area (~3.3 W continuous) regardless of internals. A vapor chamber doesn't fit and only spreads; a copper-foil + rigid-post stack can't hold pressure against a soft shell. |

## 2. Architecture (two boards + FFC)

```
 camera end ─────────────────────────────────────────────────────────────── USB end
 PNM-MAIN (45×44 mm pebble cap, 4L 0.8 mm)   battery bay   PNM-PWR (41×39 mm + USB tongue)
  top:  Core1106-1408 (RV1106G3 + WiFi/BT)    ≤7×20×40      top: EG800Q-NA, nano-SIM, USB-C,
        status LED, speaker/LRA pads,         LiPo           FFC, JST-GH battery, TVS, SIM ESD
        10 test pads                                          btm: BQ24074, LC709203F gauge,
  btm:  nRF52840 (MDBT50Q), 2 mics, amp,                           FSUSB42 USB mux, 2× TXB0104,
        DRV2605L, load switch, camera FPC,                         AT42QT1011 touch, U.FL, 12 TPs
        FFC, Tag-Connect SWD
        └──────── 30-way 0.5 mm FFC, straight-through, runs UNDER the battery ────────┘
```

**Power.** USB-C → BQ24074 (1.21 A input limit, 270 mA charge) → VSYS (3.5–4.4 V).
- VSYS feeds the Core1106 (through the TPS22917 load switch; the module's own PMIC accepts 2.7–5.5 V), the nRF VDDH, the MAX98357A and the DRV2605L.
- The modem runs from VBAT with 2×47 µF, a TVS and an HF cap array, as Quectel recommends.
- The nRF52840 runs in high-voltage mode, and its REG0 output is the always-on 3.3 V rail (+3V3_AON, ≤25 mA).

**Control.** The nRF52840 is the always-on wake island. It owns:
- the PDM wake mic
- SoC power (enable and reset) and wake/IRQ lines
- the modem's PWRKEY, RESET, STATUS, RI and DTR
- the I²C bus to the haptic driver and fuel gauge
- the USB mux select
- the touch input, charge status and RGB LED

**Data.**
- SoC ↔ modem: USB 2.0 through the FSUSB42 mux (SEL=1). The default, SEL=0, routes the SoC's USB to USB-C for flashing and ADB. There's also a 4-wire UART5 link through a level shifter.
- SoC ↔ nRF: UART3.
- Camera: MIPI-CSI, 2 lanes.
- Audio out: I²S to the MAX98357A.
- Audio in: an analog MEMS mic into the RV1106 codec for session audio.

**Inter-board FFC (30P, pin n ↔ pin n):**

| Pin | Net | Pin | Net | Pin | Net |
|---|---|---|---|---|---|
| 1 | GND | 11 | MDM_RXD_3V3 | 21 | MDM_STATUS |
| 2–5 | VSYS (4×0.5 A) | 12 | MDM_TXD_3V3 | 22 | MDM_RI |
| 6, 7 | GND | 13 | MDM_RTS_3V3 | 23 | MDM_DTR |
| 8 | USB_SOC_DP | 14 | MDM_CTS_3V3 | 24 | USB_SEL |
| 9 | USB_SOC_DN | 15 | GND | 25 | CHG_N |
| 10 | GND | 16 | +3V3_AON | 26 | VBUS_DET_3V3 |
| | | 17, 18 | I2C_SCL / SDA | 27 | TOUCH_OUT |
| | | 19, 20 | MDM_PWRKEY / RESET | 28 | +3V3_SOC |
| | | | | 29, 30 | GND |

### Design rules that firmware and bring-up must respect
1. **Program UICR.REGOUT0 = 3.3 V** on the nRF's first boot; the factory default is 1.8 V. Configure P0.18 as PSELRESET.
2. **Leave Core1106 pins 60/61/62/67 and 63/64/68/69 unused.** On the Wi-Fi variant they are tied through 1 kΩ to WL_EN/HOST_WAKE or carry the BT UART (Luckfox schematic).
3. **No back-powering.** While SOC_EN is low, the nRF must hold every SoC-facing line low or Hi-Z. The modem-UART translator's VCCB is +3V3_SOC, so it switches off along with the SoC.
4. **Charge termination.** The modem loads VBAT directly, which can block termination while charging. Keep the modem in DRX/sleep while on USB, or accept timer-based termination.
5. **Default USB mode.** The SoC's USB comes up routed to USB-C. Host mode toward the modem needs a device-tree role switch (usb-role-switch).

## 3. What stretches the boards

Courtyard areas from the placed PCBs:

| Board (area) | Biggest items | Why it's fixed |
|---|---|---|
| **PNM-MAIN** (1651 mm²) | Core1106 32×32 (**1023 mm², 62%**); nRF module 16.6×11.6 (192); FFC 21.2×8 (169); camera FPC 16.2×8 (129) | The Core's underside parts force a **24.2×21.3 mm cutout** through the carrier, so ~515 mm² of the *bottom* side under it is unusable. Everything else has to crowd into an L-shaped strip 6–12 mm wide around it. |
| **PNM-PWR** (1185 mm²) | EG800Q-NA 18.8×16.9 (**317**); nano-SIM 14.7×15.5 (**228**); FFC 21.2×8 (169); USB-C 10.7×9 (97); JST-GH 7×6.5 (46) | The modem alone is taller (17.7 mm) than K's whole lower bay (~16 mm). The SIM holder is nearly as big as the modem. The FFC connector (2.0 mm tall) can't go underneath, where there's only 1.5 mm of clearance. |

Length budget along the device (L interior ≈ 94 mm):
- main board: 45 mm (Core 30 mm plus a 6 mm nRF/FFC strip and an 8 mm top cap)
- battery: 21 mm
- power board: 26 mm (modem row 17 mm, FFC/battery-connector row 8 mm)
- USB tongue: in the channel

**Shrinking the boards, most to least effective:**
1. **Bare RV1106G3 instead of the Core1106** (Rev B): recovers the ~515 mm² cutout and the module's 1.6 mm PCB. It's the only change that gets back toward 1000+ mAh. The cost is the risk you chose to defer.
2. **MFF2 eSIM (5×6 mm) instead of the nano-SIM**: saves ~220 mm² on PNM-PWR. You'd lose SIM swapping on the bench, and the eUICC needs provisioning.
3. **Solder the battery leads instead of the JST-GH**: saves ~46 mm².
4. **Custom low-profile FPC connectors** (≤1.0 mm, e.g. Hirose FH19C class): would let the FFC move to the underside. That needs new footprints; there are no stock KiCad ones.

## 4. What keeping K's exact size would have cost

K interior is ~84 mm long; L adds 10 mm. At K length, one of these has to give:
- **Keep this layout:** the battery bay shrinks from 21 to ~11 mm, about **250–300 mAh**, roughly half of L.
- **Or keep ~450–500 mAh** by taking items 2–4 above together:
  - an eSIM instead of the removable nano-SIM
  - battery leads soldered directly
  - no modem keep-out margin, which makes rework harder
  - low-profile connectors that need custom footprints

  That's still ~20% less battery than L.

What L gives you: ~550–600 mAh (2.0–2.2 Wh), which works out to about 40 min of continuous LTE talk at ~3 W, or ~30 h of registered-idle standby at ~18 mA. These are estimates to bench-measure, not results. Keep in mind that the old "2000 mAh / ~10 h" figure never fit K either.

## 5. Bench plan

### Phase 0: dev kits (buy now, no custom boards)
Each item matches a Rev A part so code and wiring carry over.

| Item | Why | ~$ |
|---|---|---|
| Luckfox **Pico Ultra W** (RV1106G3 + WiFi6/BT5.2) | Same SoC and radio family as Core1106-1408. Answers the A2DP-on-BT5.2 question. | 30 |
| Luckfox **SC3336 3MP Camera (B)** | Same Luckfox 20P pinout as J4 on PNM-MAIN | 9 |
| **Quectel EG800 EVB, NA variant** (DigiKey), or skip and bring up on a PNM-PWR | Same modem and AT set as Rev A. The Electromaker listing is the EU variant. | EVB |
| Adafruit **Feather nRF52840 Express** (MDBT50Q-1MV2) | Same module as U3. Wake word, UART to SoC, power sequencing. | 25 |
| MAX98357A (Adafruit 3006), DRV2605L (Adafruit 2305) + Vybronics **VG1040003D**, PUI **AS01508MR-LWC40** | Audio and haptics chain as on the board | ~25 |
| BQ24074 (Adafruit 4755) + LC709203F gauge breakout + a 500–600 mAh 1S cell | Power path and fuel-gauge firmware | ~25 |
| US IoT nano-SIM (Hologram or Soracom plan-US), U.FL LTE antenna (Molex 2091420180) + pigtail | Real network attach on US bands | ~15 |
| Tag-Connect TC2030-CTX-NL + SWD probe | Same programming path as Rev A | ~40 |

**Numbers Phase 0 must produce before fab:**
- wake-to-first-audio, with the modem in registered-idle vs. powered off
- idle current (target < 20 mA)
- modem TX peak current and VBAT droop
- whether A2DP to earbuds works on BT5.2
- whether RV1106 runs app + camera + modem at once
- SoC-surface temperature over a 60 s session

### Phase 1: Rev A boards (after routing)
- **Fab:** 4-layer, 0.8 mm, ENIG, 0.1/0.1 mm rules, controlled impedance for USB (90 Ω), MIPI (100 Ω) and a 50 Ω RF feed. JLC assembles everything except the Core1106, which is a hand-solderable stamp-hole module. The EG800Q LGA must be machine-placed.
- **Bring-up order:**
  1. VBUS/VSYS on a current-limited supply
  2. nRF (SWD, UICR, +3V3_AON)
  3. SoC_EN → Core boot on USB-C (ADB)
  4. camera
  5. audio
  6. modem PWRKEY → AT over USB (USB_SEL=1) → attach
  7. touch
  8. charge
- **Fit:** check the PLA fit of the L prototype with dummy boards (the exported STEPs) before installing a live battery.

## 6. Requirements for enclosure L

Everything is in [`mechanical/enclosure-L-electronics.json`](mechanical/enclosure-L-electronics.json), in K's axes.

0. **Construction:**
   - Two soft shells, front (+z, outward: camera, touch, LED) and rear (skin side, kept insulating), in silicone or TPU, 0.8–1.2 mm walls. **No aluminum frame.**
   - A rigid internal carrier (PC, nylon or PA12) locates the boards, battery, speaker, LRA and camera, and takes the M1.6 screws. The shells seal and cushion around it.
1. **Length +10 mm:** insert a straight section at y = −10. The camera end is unchanged; everything at the USB end moves −10 mm, so the interior spans y −59…+47.6.
2. **Board supports:**
   - PNM-MAIN underside at **z 4.7** (top 5.5). PNM-PWR underside at **z 4.0** (top 4.8).
   - Rear floor stays at z 2.45. The lowest parts sit at z 2.56 (main-board FFC connector) and z 2.66 (power board).
   - M1.6 holes: main (−11.8, 41.5) and (12.8, 41.35); power (15.6, −21.6) and (−19.8, −22.6).
   - Use a rigid frame-referenced carrier, not screws into TPU (same guidance as K).
3. **Headroom over the Core:** extend the camera-bump pocket down to y ≈ 2.5 so everything stacked on the Core fits:
   - speaker Ø15×3.5 at **(−8, 12.4)**, top z 12.1 — nudged +2.2 mm so it clears the touch pad
   - LRA Ø10×4 at **(−10.5, 30.5)**, top z 12.6 (moved off the Core1106 Wi-Fi/BT chip antenna at x 10.5–13.7, y 10.5–13.5)
   - SoC thermal post
   - camera envelope: 11×11×6 mm on the 30° axis at K's aperture (0, 26, 16.8)
4. **Battery pocket (LP702040, 7.0×20×40 mm):** x −20.4…19.6, y −19.3…1.3, z 2.85…9.85, with the FFC (16.5 mm wide) underneath at z 2.5–2.8. The FFC needs an S-bend clearance at PNM-PWR J5: y −21.4…−19.3, z up to 6.8.
5. **USB-C:** mouth at y −58.8, centre z **6.46** (K had 6.1). The exterior wall around the port must be thin or counterbored so a standard plug (overmold ~12.4×6.5) seats fully.
6. **Openings in the front skin:**
   - mic ports above MK1 (−15.9, 17.3) and MK2 (−15.9, 22.1), with gaskets
   - speaker vents over (−8, 10.2)
   - LED light pipe at (0.7, 44.3)
   - **touch pad: 24 × 16 mm electrode on the front membrane's inner face, x −12…12, y −12…4** — i.e. ~10 mm below the camera bump's lower edge. Spring contact to **PNM-MAIN TP11** at (11.0, 4.6); the AT42QT1011 front-end (U6) is on the main board beside the nRF, so the electrode run is short and TOUCH_OUT no longer crosses the FFC
7. **RF:**
   - No copper or metal in the keep-out at x 9–23.5, y 2–16. That covers the nRF chip antenna and the Core1106 Wi-Fi/BT antenna.
   - **LTE antenna pockets** in the soft USB-end wall on either side of the USB channel: x −21…−7.5 and 7.5…18, y −50.5…−47, z 3–10. This only works because there's no metal frame. The FPC antenna part is still to be picked.
8. **Thermal — no spreader, no cutting.** Numbers from [`kicad/tools/thermal_estimate.py`](kicad/tools/thermal_estimate.py):

   | | |
   |---|---|
   | Skin area 186 cm², to-air ≈ **5.4 K/W** | **43 °C skin is reached at ~3.3 W continuous** — that ceiling is set by surface area, not by anything inside |
   | Device heat capacity ≈ 72 J/K, time constant ≈ 6 min | **A 60 s session at 3 W lifts the whole device ~2.3 K** |
   | Modem → shell across a bare 1.5 mm air gap | +8 K at 60 s, but **+36 K at 10 min** |
   | Same step with **one silicone gap pad** | +0.5 K |

   So the burst interaction needs no thermal hardware at all, and the gap pads exist for sustained modes.
   - **The PCB is the spreader.** 4-layer copper goes isothermal in milliseconds. Routing must put a thermal via field under the EG800Q-NA ground pads into both inner planes, stitch the Core1106 GND stamp pads in, and not neck inner copper around the modem. Zero parts, zero assembly.
   - **Two off-the-shelf silicone gap pads**, ≥3 W/mK, 3 mm, pre-cut squares: one on the modem lid (x −15…−3, y −42.5…−31), one on the Core1106 top between the LRA and camera (x −5…2, y 31…37). Compressible, so they absorb the tolerance of a soft shell — which a rigid post cannot. Non-conductive, so unlike copper they impose no antenna or touch keep-outs.
   - **Firmware duty limiting is the real control**, because the ceiling is skin area.
   - **If the bench disagrees:** cast the front shell in thermally conductive silicone (k 1–3, no extra parts, just a different material at mould time), or peel-and-stick pre-cut graphite pads inside the front shell.
   - **Rejected:** the ATS-VC-042 vapor chamber (100 × 40 × 3 mm, 18 g, rated 124 W) — longer than the cavity, no 3 mm layer spare, and it only spreads. Also rejected: the copper-foil + shim-post + putty stack I specced first. It was fiddly to assemble and depended on a rigid post holding pressure against a silicone wall.

## 7. Open items (not frozen, need a decision or a measurement)
- **Routing** both boards: impedance-controlled USB, MIPI and RF; power pours; via-in-pad under the LGA. This is the next KiCad task.
- **LTE antenna part:** pick an FPC antenna (698–2700 MHz, MHF1 pigtail) that fits the USB-end pockets (§6.7), then tune the pi-match. With the metal frame gone this is ordinary RF work. The bench uses an external antenna on the U.FL.
- **CAMERA MODULE — not chosen, and it blocks enclosure L.** The PCB is unaffected (J4's 20P pinout is frozen and every option below uses it), but the bump cannot be modeled until this is settled:
  - **The choice of sensor is much wider than Luckfox's "supported" page suggests.** Their RV1106 SDK ships ISP tuning (IQ) files for `sc3336, sc3338, sc2336, sc230ai, sc231hai, sc200ai, sc4336, sc401ai, sc500ai, sc501ai, sc530ai, sc301iot, gc2053, gc1084, gc2093, gc4023, gc4653, mis2032, mis5001, os02h10, os02k10, os04a10, imx415, sc031gs`, and the SDK kernel carries ~150 sensor drivers. **GC2053 is tuned and supported**, which matters because it's the sensor in most small MIPI FPC modules sold for RK/RV platforms.
  - **Height comes from the lens, not the sensor.** The Waveshare (A)/(B) are ~22 mm tall because of an M12 holder; Hampo's GC2053 module is 18.6 mm because of a 150° F1.9 lens. A 90–110° board lens on the same sensor is far shorter.
  - **What the mechanics actually allow** (measured by sweeping solid clashes, not estimated). The limit is *not* the bump — it's the Core1106 top at z 8.42, the speaker and the LRA sitting right under the module:

    | Bump growth | Largest module that clears |
    |---|---|
    | none | **12 × 12 × 6 mm** (11 × 11 × 6 with the LRA where it is now) |
    | +1 mm | 16 × 16 × 6 mm |
    | +2 mm | 16 × 16 × 7 mm |
    | +3 mm | 16 × 16 × 8 mm |
    | +4 mm | 16 × 16 × 9 mm |

    Anything past 12 × 12 also needs the LRA moved off the camera footprint.
  - **Option A — ship the SC3336 (B) ($9, verified):** needs a Ø14 × 22 mm angled barrel housing. No sourcing, but it's a periscope, not a wearable bump.
  - **Option B — board-lens FPC module (recommended):** RFQ ready to send in [`CAMERA-RFQ.md`](CAMERA-RFQ.md). any sensor from the tuned list above, ≤12 × 12 × 6 mm, 90–110° FOV. Module houses (Sincere, Hampo, CK Vision, Sinoseen) quote at MOQ 3–10. Send them the envelope, the FOV and the pinout; ask for the shortest board lens they stock.
  - **Option C — drop the 30° tilt:** shortens the bump, changes the framing K was designed around.
  - **Connector caveat:** J4 is 20P on the Luckfox pinout, which is what the bench (B) uses. Many compact modules are **24P**. Regenerating J4 for a 24P module is a small change to `design.py`, but the module's drawing and pinout have to come first.
- **Thermal numbers:** skin temperature over a 60 s and a 10 min session, with and without the copper spreader (Phase 0 mock-up: copper tape inside a printed TPU shell).
- **Speaker acoustics** (front volume, vents) — note the vents now sit just above the touch pad.
- **Sustained-mode thermals:** 10 min at 3 W is where the gap pads and duty limiting earn their place. Measure it in Phase 0 before deciding whether the front shell needs conductive silicone.
- **Touch sensitivity:** the battery pouch is ~1–2 mm behind the pad's lower half and the speaker sits just above it; both reduce sensitivity. Tune C25 (Cs) against the final electrode, and consider a foam spacer to hold the electrode off the metal.
- **RF pi-match** R14/C13/C14 values, tuned on the real antenna.
- **Passive specs** in the CSVs are value + footprint only. Use X5R/X7R ≥6.3 V (≥10 V on VBUS/VSYS bulk) and 1% resistors. Pick LCSC part numbers at order time.

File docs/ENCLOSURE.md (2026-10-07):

# Pneuma — Enclosure, Thermal & RF (mechanical design)

> **Current prototype:** [Enclosure K mechanical interface](../hardware/mechanical/README.md) describes the perimeter-frame/soft-membrane design. The unibody and stacked-board assumptions below are historical and require reconciliation before PCB fabrication.

The body is not just a shell — it is the **heat exchanger**, the **waterproof
barrier**, and part of the **antenna system** all at once. These three jobs
interact, so they're designed together here. Rationale tie-ins:
[`ARCHITECTURE.md`](ARCHITECTURE.md) §6 + ADR-0006/0007;
[`RESEARCH.md`](RESEARCH.md) §thermal.

Status: **design.** Enclosure is intended to be iterated (3D-printed first).

---

## 1. Aluminum body as the heat exchanger

Approach (cf. iPhone 17 Pro: metal mass + heat spreader): conduct heat from the
hot parts into the aluminum unibody and let the whole body radiate.

**What gets hot (strap these, ignore the rest):**
1. **Cellular modem PA during TX** — ~0.7–0.8 A ≈ ~3 W while connected. #1 source.
2. **Linux SoC** (A7 + NPU during a session). #2.
3. Camera (brief), battery (while charging).

**Thermal path:** modem PA + SoC → thermal interface material (TIM/pad) →
graphite spreader → **aluminum unibody**.

**Why it works here:** on-demand bursts (30–60 s) dump little energy into a
comparatively large metal mass → temperature barely rises; the body soaks and
re-radiates afterward. *Continuous* operation overruns thermal mass (what cooked
the Ai Pin); Pneuma doesn't do that (ADR-0006).

**Skin-side caveat:** the body also contacts the chest, and metal feels hot faster
than plastic (effusivity). The **≤43 °C** limit applies to the skin-facing metal.
So **radiate from the outward face; insulate / stand off the skin side** (low-
conductivity layer between hot side and skin). The thin-slab + plateau layout (§4)
does this structurally: hot parts live in the **outward aluminum plateau**, the
skin side is the **cool battery slab**. Short bursts likely stay well under the
limit; design for the long-session case anyway.

---

## 2. Waterproofing (target IP68)

A printed **silicone gasket** compressed between **two aluminum shells** seals the
body (target IP68). Anodize the aluminum (scratch/corrosion); the silicone can
extend into an external **bumper** for drop protection. Four things sealing
touches, designed back in:

- **Acoustic membranes** over the mic and speaker (Gore/Saati) — pass sound, block
  water. One also serves as the **pressure-equalization vent** a sealed device
  needs.
- **USB-C charging + data** (chosen over portless Qi/pogo): Qi won't pass the
  aluminum body, and a data port is worth keeping — flashing the Linux SoC,
  dev/debug, recovery from a bad OTA, and a non-cellular firmware-update path. The
  cost is that the port is the one genuine waterproofing weak point; solve it the
  way IP68 phones do — a **gasketed/waterproof USB-C receptacle** sealed to the
  PCB so water can enter the cavity, drain, and never reach the interior, with the
  silicone gasket **wrapping the opening**.
- **RF window = the gasket** — a real **slot/aperture in the aluminum**, filled by
  the RF-transparent silicone gasket, both seals and lets the antenna radiate
  through (§3).
- **LED indicator window** — an *optical* gap: a clear polycarbonate insert or
  **translucent silicone** over the LED (so the gasket glows), or a sealed
  light-pipe. Sealed either way.

**Whole-body heat — a thermal-break caveat:** silicone between the two aluminum
shells is a *thermal break*, so heat strapped to the plateau shell won't flow into
the other shell on its own. Either **accept it** (with on-demand bursts the
plateau shell has ample surface — start here) or **bridge it** with a small
metal-to-metal contact / thermal strap across the gasket at one spot (more sealing
complexity). Decide from bench data.

(Conduction-only cooling is unaffected by sealing — there's no airflow at this
scale regardless, so waterproofing doesn't hurt the thermal design.)

---

## 3. Antenna vs. aluminum body — the central RF tension

**A sealed aluminum body is a Faraday cage; the antenna cannot live inside the
metal.** The fix: a real **slot/aperture in the aluminum**, filled by the
RF-transparent **silicone gasket itself** (one part, two jobs — seal + RF window),
with the FPC antenna behind it. (Like the plastic antenna breaks in phone metal
frames.)

**Tuning caveat:** the antenna must be tuned *with the metal aperture present* —
the surrounding aluminum edges become part of its electrical picture (the slot can
radiate/detune), so expect an RF simulation-and-tweak pass during bring-up rather
than dropping in a generic FPC antenna.

**It competes with the thermal radiator for the outward face.** Resolve in 3D:
- **Aluminum body** = structural mass + radiator (outward + sides).
- **RF window** = plastic section at the **top or bottom edge**, positioned *away
  from the body* (better SAR, less tissue detuning), FPC antenna behind it, PCB
  ground + battery shielding toward the chest.

Get these two zones not overlapping/fighting and the layout resolves.

**Antenna size — how small can you go?** Two regimes:
- **Self-contained radiators** keep full LTE band (incl. 700 MHz): the 85×14.5 mm
  **flex** (Molex 2091420180, plug-and-play U.FL — prototype) or, on the product PCB,
  the **~40×7×3 mm Pulse W3796** SMD (full 698–2700 MHz, >65% eff., needs a ground-
  plane keepout). The W3796 ~halves the footprint → a smaller **~45×12 mm RF window**,
  leaving *more* aluminum for the heat spreader (same direction as the thermal goal).
- **Ground-plane boosters** (tiny chips, e.g. Ignion NN03-310, 30×3×1 mm) go smaller
  still but use the PCB ground as the radiator and want a **~100 mm** ground plane;
  on our 80 mm body, low-band efficiency drops — skip unless you accept mid-band-only.

So: **prototype on the flex, ship the ~40 mm W3796** on the PCB (still no chassis RF).

**Antenna technology — and how hard the "frame antenna" really is.** The Molex
adhesive flex is the *prototype* antenna (cheap, no tooling, on-air in a day; a
0.1 mm ribbon that hides along an edge). The product-grade options, easiest → hardest:

1. **Flex (FPC)** behind the non-metal RF window — prototype + early product; tune
   empirically with a VNA.
2. **Ground-plane-coupled chip antenna** (e.g. Ignion "Virtual Antenna" / mXTEND, or
   Taoglas/Antenova with their tuning service) — tiny standard SMD that uses the PCB
   ground as part of the radiator; the vendor helps tune. *Near-frame performance
   without DIY chassis RF — the recommended "integrated" step.*
3. **LDS antenna** lasered onto a plastic carrier / the window insert — the
   smartwatch standard; needs a vendor + volume.
4. **Hybrid frame** — keep the body grounded as the heat spreader, but isolate **one
   plastic-broken segment** of the frame as the radiator, fed by a flex. Many
   products that *look* like frame antennas are actually this.
5. **Full metal-frame/slot antenna** (phone-style) — the **hardest** option:
   slot + feed + matching network + EM simulation (HFSS/CST) + anechoic-chamber
   tuning, tightly coupled to frozen mechanics, with body-proximity detuning and
   SAR complications on the surface you touch. *Endgame only, with an RF engineer —
   not a prototype or DIY-blind path.*

So: **ship on flex; if you want the integrated look, hire the tuning out** (a
ground-coupled chip or LDS) rather than hand-rolling a chassis antenna.

---

## 4. Form factor & size — thin slab + plateau (iPhone-Air-style)

**Envelope: ~40 × 80 mm footprint**, but *not* a uniform 20 mm brick. Instead two
zones:

```
        ┌──────── plateau / bump ────────┐   ← ~14–18 mm
   ┌────┤  camera · SoC · modem · speaker├─────────────────┐
   │    └────────────────────────────────┘                 │  ← thin slab ~8–10 mm
   │  battery slab + PCB                                    │
   └───────────────────────────────────────────────────────┘
     (skin side)
```

- **Thin slab (skin side):** battery + main PCB. Flat, cool, comfortable against
  the chest.
- **Plateau / bump (outward):** camera (lens depth), speaker (~3–5 mm cavity), SoC,
  modem — the parts that need vertical room.

This maps to a **two-board stack** — a main/battery board in the slab and a
SoC+modem board in the plateau, joined by one board-to-board connector or short
flex; camera/antenna/speaker/mic/USB-C hang off on flex/JST (see BOM interconnect).

**Battery dimensioning** (the slab is the battery): the standard off-the-shelf cell
is **~8 × 36 × 60 mm / 2,000 mAh** (e.g. PKCell LP803860, single-unit orderable) →
thin section ≈ 10–11 mm. A thinner/longer cell (~5–7 × 36 × ~72 mm, same ~2,000–
2,500 mAh) is a **custom/volume** option if you want to slim the slab further.

**Thermal payoff:** put the hot parts (**modem PA + SoC**) in the **outward
aluminum plateau** → the bump radiates *away from the body* while the cool battery
slab sits against the skin. This resolves the radiator-vs-skin-contact tension by
geometry (see §1).

**Wearability:** average thickness well under 20 mm; a deliberate design language,
not a brick. Levers to slim further later: **iSIM**, smaller battery (the
on-demand model tolerates it), PCB stacking / flex-rigid, aluminum body as
structure.

---

## 5. Enclosure openings (cutout sizes)

Design-start sizes for every penetration, from the BOM parts. **Authoritative
cutout = each part's datasheet "recommended panel cutout" / STEP** — confirm before
final CAD. Every opening must be sealed by its matching method.

| Opening | Cutout | Sealing | Notes |
|---|---|---|---|
| **USB-C** | mouth ~9.0 × 3.3 mm; plug recess ~12 × 7 mm | connector IP67 flange + gasket | Thin wall (≤~2 mm) / counterbore so the cable overmold seats. GCT USB4500 datasheet is authoritative. |
| **Camera** | ~6 mm Ø aperture; clear window ~8 mm Ø | sealed clear window (sapphire/PC) | Clears SC3336 lens + ~98° FOV; chamfer inner edge to avoid vignetting. |
| **Antenna** | RF window ~85×15 mm (proto flex) or **~45×12 mm** (product W3796 SMD) | gasket fills it (RF-transparent) | Smaller antenna → smaller window → more metal body (§3). |
| **LED** | ~3 mm Ø window (or 1.5–2 mm light-pipe) | clear/translucent insert or translucent silicone | Light-pipe keeps the LED off the surface. |
| **Mic** | ~1.0 mm Ø port | waterproof acoustic membrane | Membrane also serves as the pressure-equalization vent. |
| **Speaker** | grille ~5–9 × 1.0–1.5 mm holes (or ~10 mm slotted) | acoustic membrane behind grille | Many small holes seal better than one big hole. |
| **Button** | ~5 mm Ø | silicone dome / overmold over a tact switch | Or avoid the hole with a capacitive / Hall (magnet) button. |

Add 0.1–0.3 mm clearance around connectors and account for gasket compression.

## 6. Attachment / wear mode

The Humane Ai Pin used a **magnetic clamp through fabric**: the Pin on the outside,
a magnetic piece behind the cloth — either the passive **"Latch"** or the
**"Battery Booster"** (magnet + battery powering the Pin through the clothing).

**Lesson baked in:** the Booster was an *active, warm* part against the body and
reviewers found it uncomfortably hot. So if Pneuma goes magnetic, the **skin-side
piece must be a passive magnet only — never a heat source.** Our layout cooperates
(heat is in the outward plateau; the skin side is the cool battery slab).

Options: **magnetic clamp** (most "Pneuma," keep the inner piece dumb + cool),
**lanyard loop**, or a **clip**. Choose during industrial design.

## Open mechanical items

- [ ] Thermal mock-up: skin-side temp during a sustained session; size the TIM +
      graphite + Al mass; pick the skin-side insulator.
- [ ] Antenna: prototype on the Molex flex (U.FL); on the product PCB use the Pulse
      W3796 (~40×7 mm SMD, full band, ground-plane keepout) → ~45×12 mm RF window.
      Confirm placement + tuning.
- [ ] RF window material + placement; antenna efficiency/SAR with the metal body
      present; confirm no thermal/antenna face conflict.
- [ ] Seal the USB-C interface: gasketed IP67 receptacle + panel-cutout per the GCT
      datasheet; wall thinned/counterbored for plug-overmold clearance.
- [ ] Acoustic membrane parts + port geometry for mic/speaker; vent placement.
- [ ] Gasket geometry for a printed silicone seal; long-term seal/clamp design.

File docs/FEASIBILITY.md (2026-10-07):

# Pneuma — Is this device actually feasible?

**Verdict:** the *idea* is feasible. The *current spec, taken as a v1 wearable*,
is not — not because any one block is science fiction, but because the ADRs have
stacked into an Ai-Pin-class hardware program while still assuming a solo-maker
BOM and an instant "Hey Pneuma" response.

A desk prototype that talks to a realtime model over cellular is a near-term,
buildable thing. A sealed aluminum puck that wakes instantly, stays cool on
skin, runs four radios, is IP68, has no phone and no server, and works all day
in Portland is a different device. This note separates those.

Status: independent review of the design in this repo (ARCHITECTURE, RESEARCH,
BOM, ENCLOSURE), checked against datasheets and published bring-up numbers.
Not a lab measurement.

---

## 1. Three different products (do not conflate them)

| | What | Feasible? |
|---|---|---|
| **A. Desk demo** | Luckfox Pico Ultra + Cat-1 HAT + IoT SIM + laptop-proven session code, talking to OpenAI/Grok over cellular | **Yes.** Weeks to a first voice round-trip. This is the right next step. |
| **B. Personal wearable** | Custom PCB in a 3D-printed body, nano-SIM, speaker + optional earbuds, on-demand Q&A, you are the only user | **Maybe**, with 2–4 board spins and a willingness to drop IP68 / aluminum / eSIM / projection / live nav. Months of hardware, not a weekend. |
| **C. Sellable consumer device** | The full ADR stack: standalone cellular, app-less, IP68 aluminum, SGP.32, FCC/PTCRB/SAR, all-day, instant wake | **Hard.** Same class of program as the Humane Ai Pin. The architecture is *better* than the Pin's (on-demand vs continuous), but certification, RF, and wake latency are still product-scale problems. |

The repo currently describes **C** while costing **A**. That gap is the main
feasibility issue.

---

## 2. What is actually sound

These choices are right, and they are why the device is not a fantasy:

- **On-demand, not continuous.** The Ai Pin failed thermally because it was a
  phone that never slept. Bursting a session then cutting power is the correct
  lesson. Short Q&A (30–60 s) is in a different thermal regime than streaming.
- **Cloud brain, modest SoC.** Do not put a Snapdragon 720G in a pendant. An
  RV1106-class chip plus a module modem is the right size of computer.
- **Cat-1 bis for the radio tier.** Voice is tens of kb/s; Cat-1's ~10/5 Mbps
  and <100 ms typical latency are enough. LTE-M/NB-IoT are the wrong tier.
- **Opus-over-TLS-WebSocket rather than full WebRTC** as the first transport.
  A single Cortex-A7 can encode Opus. libwebrtc on 256 MB is a much worse bet.
- **OpenAI Realtime over WebSocket with the API key on-device** does *not*
  require a Pneuma server. Ephemeral tokens are a browser/WebRTC concern.
  (Stolen-device key leakage is a product risk, not a protocol blocker.)
- **On-demand camera, not always-watching.** Technically easier than live video,
  and it sidesteps the privacy backlash that hit Friend / Bee.
- **Parts exist and are orderable.** That part of the BOM work is real.
- **The earlier phone-tethered nRF design is highly feasible** — it is what Omi
  / Bee / Limitless already shipped. It was abandoned for product reasons, not
  physics.

Thermal mass for a *short* burst is also fine. A ~40 g aluminum shell
(~36 J/K) absorbing 3 W × 60 s = 180 J rises ~5 K if you ignore cooling. Skin
limit 43 °C is not the problem for a one-minute question. It *is* the problem
for a ten-minute conversation or for Spotify/nav as specified (see §4).

---

## 3. Load-bearing errors in the current spec

These are not nits. They change whether v1 works.

### 3.1 Battery math: "~10 h continuous talk" is wrong

A 2000 mAh / 3.7 V cell is **7.4 Wh**. At the stated ~3 W session:

`7.4 Wh / 3 W ≈ 2.5 hours`

LTE TX typical on the EG915U is ~0.77 A; 2000 mAh / 770 mA ≈ **2.6 h**, before
the SoC, PA inefficiency, or poor-signal current. The BOM's "~10 h+ continuous
talk" looks like 2000 mAh was divided by ~200 mA instead of ~800 mA.

**All-day is still plausible on an on-demand duty cycle** (twenty 45-second
sessions is ~15 minutes of radio time). It is not plausible as hours of
continuous talk, and it is not free: it depends on *idle* current staying in
the tens of mA, which fights full power-off of the modem (next item).

### 3.2 Wake-to-ready latency is the real make-or-break

The interaction loop assumes: wake word → earcon → converse. That only works
if the session tier is already *almost* up.

Measured / specified numbers:

| Step | Typical if fully powered off |
|---|---|
| RV1106 default Buildroot boot | **~14 s** (Luckfox Pico Ultra users) |
| RV1106 aggressively fastbooted | **~1–5 s** (research writeup ~1 s; vendor fastboot is BusyBox ramfs, read-only, little RAM left for a Rust TLS client) |
| EG915U PWRKEY + init | **≥2 s** PWRKEY low, then firmware init |
| LTE attach from radio-off | **~5–20 s** (network-dependent; multi-IMSI IoT SIMs can be worse) |
| TLS + realtime session | **1–3 s** |

**Full power-off of SoC + modem, as drawn, is a 15–40 s "Hey Pneuma."** That
is not a voice assistant. It is a walkie-talkie with a long wakeup.

The devices that feel instant (Apple Watch LTE, phones) keep the modem
**registered-idle**. EG915U idle with USB disconnected is specified around
**13 mA**. LTE sleep (paging) is ~1.2–1.6 mA. Either is thermally nothing
and still all-day on 2000 mAh.

So the feasible power architecture is **not** "cut the session tier to zero":

- **Keep the modem registered** (idle or DRX), and
- **Keep the SoC in suspend-to-RAM or a ~1 s fast path**, and
- Use the wake island for the word / button / cues.

RV1106 suspend quality is unverified (IPC chips are often weak at S3). That
is a bench item, not an ADR to accept on paper. Vendor "FASTBOOT" images
run the rootfs in DDR, drop Buildroot, and leave little room for the actual
app — they are not a free 1-second boot of the planned Rust stack.

Until wake-to-first-audio is measured under **1–3 s**, do not freeze
"SoC+modem fully off" as the product behavior.

### 3.3 The BOM modem does not cover the US

The design part is **Quectel EG915U-EU**. That SKU is EMEA/AU/NZ: LTE bands
**B1/3/5/7/8/20/28**. There is no EG915U-NA. Portland / AT&T / T-Mobile want
**B2, B4, B12, B13, B66, B71**. Sharing B5 is not coverage.

A US build needs a different module (e.g. EG915Q-NA / EG800Q-NA class, or
whatever the LilyGO/Waveshare HAT actually ships). Regional SKUs also change
certification. This is a one-line BOM fix that currently makes the production
part unusable where the project is based.

### 3.4 BM83 does not give you the AirPods microphone

ADR-0008/0009 sell the Microchip **BM83** as A2DP source **and** HFP (earbud
mic). The BM83 **Audio Transceiver (AT) v1.0** feature matrix is explicit:

- Tx mode: A2DP **source** = yes. **HFP Audio Gateway = no.**
- Rx mode: A2DP/HFP **sink** (the BM83 is the headset) = yes. HFP AG = still no.

HFP AG is the role Pneuma needs to be "the phone" and use AirPods as a
headset mic. This firmware does not do that. A2DP-out to earbuds is real;
discreet two-way via the earbud mic is not, on this chip/firmware.

The module is also **32 × 15 × 2.5 mm** with an onboard PCB antenna and a
ground-plane keepout under the module. That is a large brick to drop into a
40 × 80 mm aluminum Faraday cage that already needs an LTE window. It is a
bench-audio solution, not a "fits the puck" solution.

### 3.5 Navigation and Spotify fight the thermal thesis

ARCHITECTURE §8 adds sustained modes: nav at 0.3–0.7 W, media at 0.5–1 W,
and (optional) projection. ADR-0006's whole point is *do not generate heat
continuously*.

Natural convection from a ~40 × 80 mm body is on the order of **0.05–0.1 W/K**.
Sustained 3 W implies a **30–60 K** rise — unwearable, Ai Pin territory.
Sustained 0.5–1 W might be tolerable on the outward plateau; it is not "the
thermal problem is solved by duty cycle." Treat those modes as a later
product, or as Wi-Fi-only, not as v1 requirements.

### 3.6 Several "app-less / no server" items are not v1-shaped

- **SGP.32 eSIM** from a page the device hosts: EG915U eUICC/SGP.32 is
  firmware-gated and poorly documented; field reports of profile download
  failing on this family exist. A **nano-SIM** is the honest v1. The BOM
  already says this in the fine print; provisioning still leads with eSIM.
- **Four 2.4 GHz-adjacent radios** (LTE + nRF BLE + BM83 BR/EDR + GNSS) in
  aluminum, body-worn, with SAR: this is RF-engineer work and anechoic-chamber
  time, not a first custom PCB.
- **IP68 aluminum + gasketed USB-C + acoustic membranes + RF window** as a
  coupled problem: phones do it; a first enclosure should be plastic, IP54,
  and ugly.
- **PDM mic to two chips at once.** The interconnect diagram shows the IM69D130
  feeding the nRF always and the SoC in session. PDM is a point-to-point clocked
  bus. Real options: mux (island releases the mic), island forwards PCM over
  UART (~32 kB/s at 16 kHz/16-bit), or two mics. Pick one before schematic.

### 3.7 Software is a scaffold, and the SoC Linux is a hard target

`firmware/session` is a laptop state machine with mock HAL and a stub OpenAI
driver. That is useful. It is not evidence the RV1106 can run the stack.

RV1106 practical constraints:

- **256 MB** total. ISP/VPU buffers eat a chunk. Fine for Opus + WSS; tight
  for Chromium WebRTC.
- Luckfox userland is **uClibc / musl**, kernel **5.10** vendor tree, **not
  glibc**. Rust should target `armv7-unknown-linux-musleabihf`.
- Fastboot images the vendor documents are **BusyBox-in-RAM**, read-only, and
  explicitly cramped. They conflict with "just run the Rust app."
- BlueZ A2DP on this BSP is the reason BM83 exists; that diagnosis is
  plausible and still unmeasured on hardware.

Wake-word on the nRF52840 is feasible (Cortex-M4 + CMSIS-NN DS-CNN) but
**microWakeWord does not port**, and there is no trained "Hey Pneuma" model
in the repo. Custom KWS is a project of its own (data, FAR in cafes, power).
A button-first v1 is the way shipping pendants actually work.

---

## 4. Thermal: short bursts yes, the Pin's workload no

| Workload | Energy / power | Skin-side outlook |
|---|---|---|
| 30–60 s Q&A at ~3 W | ~90–180 J into the metal | **OK** (~few K rise); then idle to dump heat |
| 10 min conversation at ~3 W | ~1.8 kJ | **Not OK** without throttling (~tens of K adiabatic; still hot with convection) |
| Spotify / nav sustained 0.5–1 W | continuous | Maybe on the outward plateau; **not** "solved" |
| Sleep, modem idle ~13 mA | ~50 mW | Trivial |

The aluminum-as-spreader idea is right for bursts. The silicone gasket
between shells is a thermal break (ENCLOSURE already flags this). Insulate
the skin side; radiate outward. Do not promise continuous LTE.

---

## 5. Cost, honestly

~$110 of parts at qty 1 is in the right ballpark **for the electronics** if
you ignore the enclosure CNC, the BM83 keepout, and the wrong regional modem.

What the current docs underweight for **C**:

- RF matching + body-worn SAR + 4-radio coexistence
- PTCRB/GCF even with a pre-certified module (the antenna is yours)
- FCC / CE / carrier
- Tooling for aluminum + silicone gasket
- 2–4 respins (the BOM is right that this, not the ICs, is the money)

A personal **B** build can skip most of that (pre-certified module, plastic
shell, you don't sell it). A product cannot.

---

## 6. What I would actually build next

Do not start with the unibody. Freeze a *smaller* device.

1. **Desk (this month).** Luckfox Pico Ultra W + a **US-banded** Cat-1 HAT
   (not the EU EG915U) + IoT SIM. Port the session brain far enough to do
   one OpenAI/Grok realtime round-trip over cellular. Measure: boot time,
   attach time, wake-to-first-audio, TX current, CPU/RAM, A2DP if you care.
   *This single experiment answers more than another ADR.*
2. **Drop from v1:** IP68, aluminum, SGP.32, projection, live turn-by-turn,
   Spotify-over-cellular, BM83-as-HFP, "no server" as a religion if WebRTC
   becomes necessary.
3. **Keep for v1:** wake island + on-demand session, button *and* wake word
   (button first), one JPEG camera, speaker, nano-SIM, BYO key, memory file,
   plastic body.
4. **Decide cellular vs phone-tether from the desk numbers.** If attach+boot
   cannot be made to feel like 1–3 s without leaving the modem up, either
   leave the modem up (and own the idle mA) or revive the BLE-to-phone
   architecture for a wearable you can actually wear this year.
5. **Custom PCB only after** (1) has talked to a model over LTE and (2)
   A2DP (if required) is proven on the real audio path.

---

## 7. Bottom line

**Feasible:** a screenless, on-demand, BYO-LLM gadget with a camera that is
off until asked. That device can be a cellular puck *or* a phone-tethered
pendant. Physics allows both.

**Not feasible as written, for v1:** every ADR at once, instant wake from a
cold Linux SoC and a cold LTE modem, 10-hour continuous talk, US use of an
EU-only module, AirPods-mic via BM83 AT firmware, IP68 aluminum, and
app-less SGP.32.

The Humane lesson in this repo is correct. The failure mode to avoid now is
the opposite one: specifying the finished consumer object before measuring
the two numbers that decide the product — **wake-to-first-audio** and
**idle current with the modem still registered**.

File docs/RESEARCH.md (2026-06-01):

# Pneuma — Research Notes

The evidence base behind [`ARCHITECTURE.md`](ARCHITECTURE.md). Compiled from a
multi-source web research pass (May 2026). Each section notes confidence and
flags fast-changing or low-confidence items honestly. This is a *living* document
— prices, model names, and APIs in this space change month to month.

**Confidence legend:** `[high]` well-sourced / multiple sources · `[med]`
plausible, single or secondary source · `[low]` inferred or unverified.

---

## 1. Realtime / "live" speech-to-speech model APIs

The model "brain" is exposed two ways, which forces a two-tier abstraction.

### Native speech-to-speech (Tier 1)
- **OpenAI `gpt-realtime`** — GA since Aug 28 2025 (first OpenAI GA realtime
  model). Native audio in/out (single model, not a chain). **Image input yes,
  video no.** Transports: WebRTC (recommended for devices), WebSocket, SIP.
  Pricing ~$32/1M audio input tokens, ~$64/1M output. Auth: server API key +
  **ephemeral client secrets** (~2h TTL) for device/browser. `[high]`
  - https://openai.com/index/introducing-gpt-realtime/
  - https://developers.openai.com/api/docs/guides/realtime-webrtc
  - Latency: ~200–350ms first audio; ~300–600ms subsequent turns (third-party
    measured, not an SLA). `[med]`
- **Google Gemini Live API** — bidirectional native audio (30 voices, 24 langs)
  and **native video-frame input (~1 fps)** in the same WebSocket session — the
  only major API with live video input. API key + **ephemeral tokens** for
  direct device connections. Preview status; model names churn
  (`gemini-3.1-flash-live-preview` etc.). `[high]` on capability, `[med]` on
  exact current model name/pricing.
  - https://ai.google.dev/gemini-api/docs/live-api/capabilities
  - https://ai.google.dev/gemini-api/docs/live-api/ephemeral-tokens
- **xAI Grok Voice Agent API** — launched Dec 17 2025. Native S2S over WebSocket,
  **OpenAI-Realtime-API-compatible** (swap base URL to `wss://api.x.ai/v1/realtime`).
  <1s time-to-first-audio, ~$0.05/min (~half OpenAI's voice cost). `[high]`
  - https://x.ai/news/grok-voice-agent-api
- **AWS Nova Sonic (Bedrock)** — native S2S via bidirectional HTTP/2 stream;
  AWS SigV4/IAM auth; Nova 2 Sonic is current gen. `[high]`
  - https://aws.amazon.com/about-aws/whats-new/2025/04/amazon-nova-sonic-speech-to-speech-conversations-bedrock/
- **Azure OpenAI GPT Realtime** — GA (preview deprecates Apr 30 2026); WebRTC +
  WebSocket. Azure **Voice Live API** wraps realtime + Azure Speech. `[high]`
  - https://learn.microsoft.com/en-us/azure/foundry/openai/how-to/realtime-audio

### No native voice → must be composed (Tier 2)
- **Anthropic Claude** — **no native speech-to-speech or standalone STT/TTS API**
  as of May 2026. Messages API is text/vision only. "Voice mode" exists only
  inside Claude's consumer apps, not as a callable API. To use Claude as the
  brain, voice must be composed: STT → Claude Messages API → TTS. `[high]`
  - https://www.datastudios.org/post/claude-voice-features-explained-current-status-and-upcoming-real-time-updates
- **Local models (Ollama / llama.cpp)** — text only; no listening/speaking. S2S
  requires composing external STT + LLM + TTS. `[high]`
  - https://github.com/ollama/ollama/issues/11021
  - Local end-to-end option: MiniCPM-o 2.6 (real-time bilingual S2S, EN/ZH) or
    running Kyutai Moshi locally for true full-duplex. `[med]`

### Open-source orchestration / S2S stacks
- **Kyutai Unmute** — open pipeline (STT + *any* text LLM + TTS), explicitly
  "bring your own text LLM"; best OSS fit for BYO-LLM composed mode. `[high]`
  https://kyutai.org/blog/2025-07-03-tts-unmute-open-source
- **Kyutai Moshi** — open full-duplex speech-native model, ~200ms practical
  latency on an L4. `[high]` https://github.com/kyutai-labs/moshi
- **Pipecat** (frame-based VAD→STT→LLM→TTS, transport-agnostic, swap any
  provider) and **LiveKit Agents** (WebRTC + plugins, can also wrap OpenAI/Gemini
  realtime). The standard way to build BYO-LLM voice today. `[high]`
  - https://github.com/pipecat-ai/pipecat
  - https://docs.livekit.io/agents/models/realtime/plugins/gemini/

**Takeaways:** Grok being OpenAI-compatible means one driver serves both. Gemini
is uniquely able to take a live camera stream. Claude + local models require the
composed pipeline — so a universal "bring your own LLM" device *must* implement
both tiers.

*Fast-changing flags:* Gemini Live model names/pricing churn; OpenAI
`gpt-realtime-2` family mid-rollout; third-party latency numbers are not SLAs.

---

## 2. ESP32-S3 pendant hardware platform

### Seeed XIAO ESP32-S3 Sense
- **21 × 17.5 mm** thumb-size; ESP32-S3R8 dual-core LX7 @ up to 240 MHz with
  vector/ML instructions. **8MB PSRAM + 8MB flash, ~512KB SRAM.** `[high]`
- **Camera: OmniVision OV2640** (2MP, up to UXGA 1600×1200, JPEG/RGB565/YUV,
  ~125mW at 15fps UXGA, detachable; OV5640 5MP swap-in option). `[high]`
- **Mic: digital PDM MEMS** on the Sense board (part commonly cited
  MSM261D3526H1CPM — `[med]`). **Wireless: 2.4GHz Wi-Fi b/g/n + BLE 5.0.** `[high]`
- **Onboard LiPo charge management**; battery solder pads (add JST-PH for a
  3.7V LiPo). Default charge current ~100mA (not officially confirmed — `[low-med]`).
- **Price ~$14** (Sense); ~$7.50 (non-Sense). `[high]`
- Power modes (Seeed doc): modem-sleep ≈ 26.5mA, light-sleep ≈ 2.2mA,
  deep-sleep ≈ 14µA spec (real-world deep sleep higher on the Sense board). `[high]`
  - https://wiki.seeedstudio.com/XIAO_ESP32S3_Consumption/
  - https://docs.edgeimpulse.com/hardware/boards/seeed-xiao-esp32s3-sense

### Battery reality (250–500 mAh LiPo)
Engineering estimates anchored to the **Owl** project (XIAO ESP32-S3 Sense,
continuous capture+stream) which recommends 1200mAh→~8h, 540mAh→~4h, implying
~135–150mA continuous. `[high for anchor]`
- Wake-word listening (radios idle): ~30–50mA `[med]`
- BLE audio streaming: ~40–80mA avg (peaks 80–130mA) `[med]`
- Camera capture: spikes ~150–250mA for the seconds it's on `[med]`
- Wi-Fi active: ~100–240mA (much worse than BLE) `[high]`
- **Conclusion:** continuous-stream-everything ≈ 3–5h; wake-word-gated ≈ 6–12h on
  250–500mAh. A **charge-daily** device, not multi-day. `[high]`
  - https://github.com/OwlAIProject/Owl/blob/main/docs/xiao_esp32s3_sense_setup.md

### On-device wake word while streaming — feasible
- **microWakeWord** (basis of ESPHome `micro_wake_word`): streaming
  Inception/CNN on TFLite-Micro, **<10ms per 20ms stride** on ESP32-S3, needs
  PSRAM (XIAO Sense qualifies). Plenty of headroom to also stream audio (run
  inference on one core, BLE/audio on the other). `[high]`
- **ESP-SR / WakeNet9** runs on S3 but conventionally pauses after detection. `[high]`
- **openWakeWord NOT viable on S3** (seconds per frame; it's for Pi-class Linux). `[high]`
  - https://www.home-assistant.io/blog/2024/02/21/voice-chapter-6/

### Connectivity for a mobile pendant
- **BLE → companion phone = the standard** (Bee, Limitless, Friend/Omi). Lowest
  pendant power; phone does heavy lifting. `[high]`
- **Onboard Wi-Fi → cloud:** avoids phone dependence indoors but ~100–240mA and
  useless when roaming; good only for opportunistic bulk upload. `[high]`
- **Cellular/LTE (e.g. Nordic nRF9160):** true phone-free mobility but heaviest
  cost/power/size + SIM + certification; not standard for consumer pendants. `[high]`

### SoC alternatives
- **nRF52840** (Friend/Omi): Cortex-M4F, BLE5, ~1.5µA sleep, ~40–50× lower BLE
  advertising current than ESP32-S3 → month vs. ~month-vs-year battery edge. **No
  camera, no Wi-Fi, weaker ML.** Best for audio-only multi-day pendants. `[high]`
- **ESP32-S3** wins when you need camera + Wi-Fi + heavier on-device ML in one
  cheap chip — Pneuma's case — at the cost of idle power. `[high]`
- **nRF5340** — more compute, still BLE-only/no-camera. **nRF9160** — only if
  cellular is mandatory. `[med]`
  - https://blefyi.com/compare/nrf52840-vs-esp32-s3/

*Uncertainty flags:* exact XIAO charge IC/current `[low-med]`; exact PDM mic part
`[med]`; per-state mA figures are estimates that firmware choices will move
substantially `[med]`.

---

## 3. Existing open-source AI pendants

### Omi (Based Hardware) — the reference design
- **Two products trace to the original "Friend" project — don't conflate them.**
  **Omi** (Based Hardware / Nik Shevchenko) = open productivity pendant. **Friend**
  (friend.com / Avi Schiffmann) = separate, *closed* companionship pendant. `[high]`
- Hardware: DevKit1 = Seeed **XIAO nRF52840 (Sense)**, Zephyr RTOS (nRF alone,
  not nRF+ESP32). DevKit2/CV1 = **Nordic nRF5340** + 8GB flash + speaker + button
  (`[med]`, from secondary source). PDM MEMS mic, 16kHz. **ESP32-S3 appears only
  in OmiGlass** (the camera variant, with `esp32-camera`). `[high]`
- Audio: **Opus over BLE GATT notifications** — 6 Opus frames × 40 bytes (240B)
  per notification; storage records 444B; LC3 added in newer codec enums. `[high]`
- Architecture: pendant —BLE Opus→ Flutter app —HTTPS/WS→ Python/FastAPI backend
  (VAD, diarization, Deepgram STT, then LLM). App supports local/offline WAL
  buffering. `[high]`
- **On-device wake word: none found** — continuous/VAD-gated capture,
  cloud-side STT. `[med]`
- Battery: DevKit1 ~6h; DevKit2 ~150mAh, ~10–14h. Price ~$70 kit / $89 consumer.
  `[med-high]`
- **License: MIT across firmware + app + backend + hardware CAD** — one of the
  most fully-open wearables. Self-hostable backend. Markets "use the AI model of
  your choice" + ships an **MCP server**. `[high]`
  - https://github.com/BasedHardware/omi
  - Notable: Omi app ships connection drivers for *competitor* hardware
    (`limitless_connection.dart`, `fieldy_connection.dart`) — reverse-engineered
    BLE protocols. `[high]`

### Others
- **Limitless Pendant** — coin-size, beamforming mic array, BLE+Wi-Fi, ~100h
  battery (stores locally, batch-syncs), visible always-on LED, "Consent Mode"
  (voice-ID pauses for new speakers). **Closed.** Acquired by **Meta, Dec 5 2025.** `[high]`
- **Bee** — $49.99 + sub, 7-day battery, always-on, BLE-offload to phone.
  **Acquired by Amazon, Jul 2025.** Closed. `[high]`
- **Plaud** — cloud LLM wrapper (GPT/Claude). Closed (third-party `openplaud`
  exists). `[high]`
- **Friend (friend.com)** — $99–129 always-listening companion, Claude-powered,
  closed; heavy privacy backlash (defaced subway ads). `[high]`
- **ADeus** — MIT, fully open, XIAO ESP32C3 / Coral / Pi Zero, Supabase
  self-host, BYO-LLM. `[high]` https://github.com/adamcohenhillel/ADeus
- **xiaozhi-esp32** — popular MIT ESP32-S3 AI chatbot, **MCP-based,
  model-agnostic**, on-device wake word. `[high]` https://github.com/78/xiaozhi-esp32

### Lessons for Pneuma
- **On-demand (push-to-capture) sidesteps the category's biggest failure** —
  the always-on surveillance backlash that tainted Friend/Bee. Lead with it. `[high]`
- Still need a deliberate, visible **capture indicator** (consent table-stakes). `[high]`
- **Opus over BLE** for audio; **camera over Wi-Fi/BLE-burst** (OmiGlass jumped
  to ESP32-S3+Wi-Fi for images). `[high]`
- BYO-LLM precedents to copy: Omi (MCP + "model of your choice"), xiaozhi (MCP),
  ADeus (BYO-LLM + self-host). **MCP is the emerging provider-agnostic glue.** `[high]`
- **Vendor lock-in/brick risk is real** (Rewind app killed Dec 2025; Bee→Amazon,
  Limitless→Meta). Open + self-hostable + BYO-key is a concrete trust advantage. `[high]`
- **License bar: MIT across firmware+app+backend(+hardware)** — anything less
  reads as "open-washing" to this audience. `[high]`

*Uncertainty flags:* exact MEMS mic part numbers (no public BOM) `[low]`;
DevKit2 nRF5340 from secondary source `[med]`; Limitless internal chipset
undisclosed `[low]`.

---

## 4. Screenless audio output

### Micro-speaker + I2S amp (recommended)
- **MAX98357A** — I2S Class-D, 1.8W into 8Ω, 2.5–5.5V, ~2.4mA quiescent. Best if
  the SoC outputs I2S (ESP32-S3 does). Breakout ~$5.95. `[high]`
  https://www.analog.com/media/en/technical-documentation/data-sheets/max98357a-max98357b.pdf
- **PAM8302** — analog-input alternative, 1.5W into 8Ω, ~$3.95 (needs a DAC if
  SoC is I2S-only). `[high]`
- **20mm 8Ω micro speakers** ~$1–2. `[high]`
- Power: amp idle trivial; playback ~0.3–1W → ~100–300mA peaks during speech. `[med]`
- **Intelligibility:** fine in a quiet room; **degrades fast in noise** —
  confirmed by Humane Ai Pin reviews ("struggled to hear it on NYC streets,"
  "tinny at louder volume"). Not private — bystanders hear it. `[high]`
  https://www.engadget.com/the-humane-ai-pin-is-the-solution-to-none-of-technologys-problems-120002469.html

### Bone conduction — rejected for a pendant
- Needs **firm bone contact**; works in glasses/headbands because they clamp the
  skull. Adafruit #1674 transducer (8Ω, 1W). `[high]`
- **Research rates the collarbone the worst location** for bone conduction;
  energy transfer "drops exponentially" with loose contact. A free-hanging
  necklace can't maintain the contact → degrades into a weak, leaky air-conduction
  buzzer — worst of both worlds. `[high for collarbone-worst; med-high inference
  for the pendant case — no study tested a free-hanging pendant directly]`
  https://www.sciencedirect.com/science/article/abs/pii/S0003687010001523

### Verdict
| Criterion | Micro speaker | Bone conduction |
|---|---|---|
| Intelligible worn loose on chest | **Yes** (quiet); degrades in noise | **No** (needs skull contact) |
| Privacy | Poor | Good *only if* skull-coupled (not a pendant) |
| BOM (breakouts) | ~$5–8 | ~$12–16 |

**Micro-speaker is the only reliably intelligible option for a necklace.**
Parametric/"audio spotlight" is genuinely directional but too large/power-hungry
to miniaturize into a pendant today. True privacy on a pendant practically means
Bluetooth-earbud fallback — which fights the "no earbuds" goal. `[high]`

---

## 5. Wake word & screenless interaction
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

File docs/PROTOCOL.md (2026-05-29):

# Pneuma — Internal Interfaces

With no phone and no app, the important seam is **inside** the device: between the
always-on **wake island** (MCU) and the on-demand **session brain** (Linux SoC).
This is the contract the two firmwares must share. (The earlier phone↔app BLE
protocol is gone with the companion app — see ADR-0004.)

Status: **draft v0** (pre-implementation; expect revision after bench bring-up).

---

## Wake island ↔ Session SoC

Physical link: **UART** (control) + a **power-enable GPIO** (wake island → PMIC/SoC).

### Power control
- `SOC_EN` (GPIO, wake island → PMIC): assert to boot/resume the SoC + permit
  modem power; deassert (after the SoC acks "sleep") to cut the session tier.

### Control messages (UART, line- or TLV-framed)

Wake island → SoC:
| Msg | Meaning |
|-----|---|
| `WAKE reason=wakeword` | wake word detected — start a session |
| `WAKE reason=button tap\|double\|long` | button event |
| `BATT level=NN` | battery state (if the gauge is on the island) |
| `CANCEL` | user dismissed / timeout before SoC ready |
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

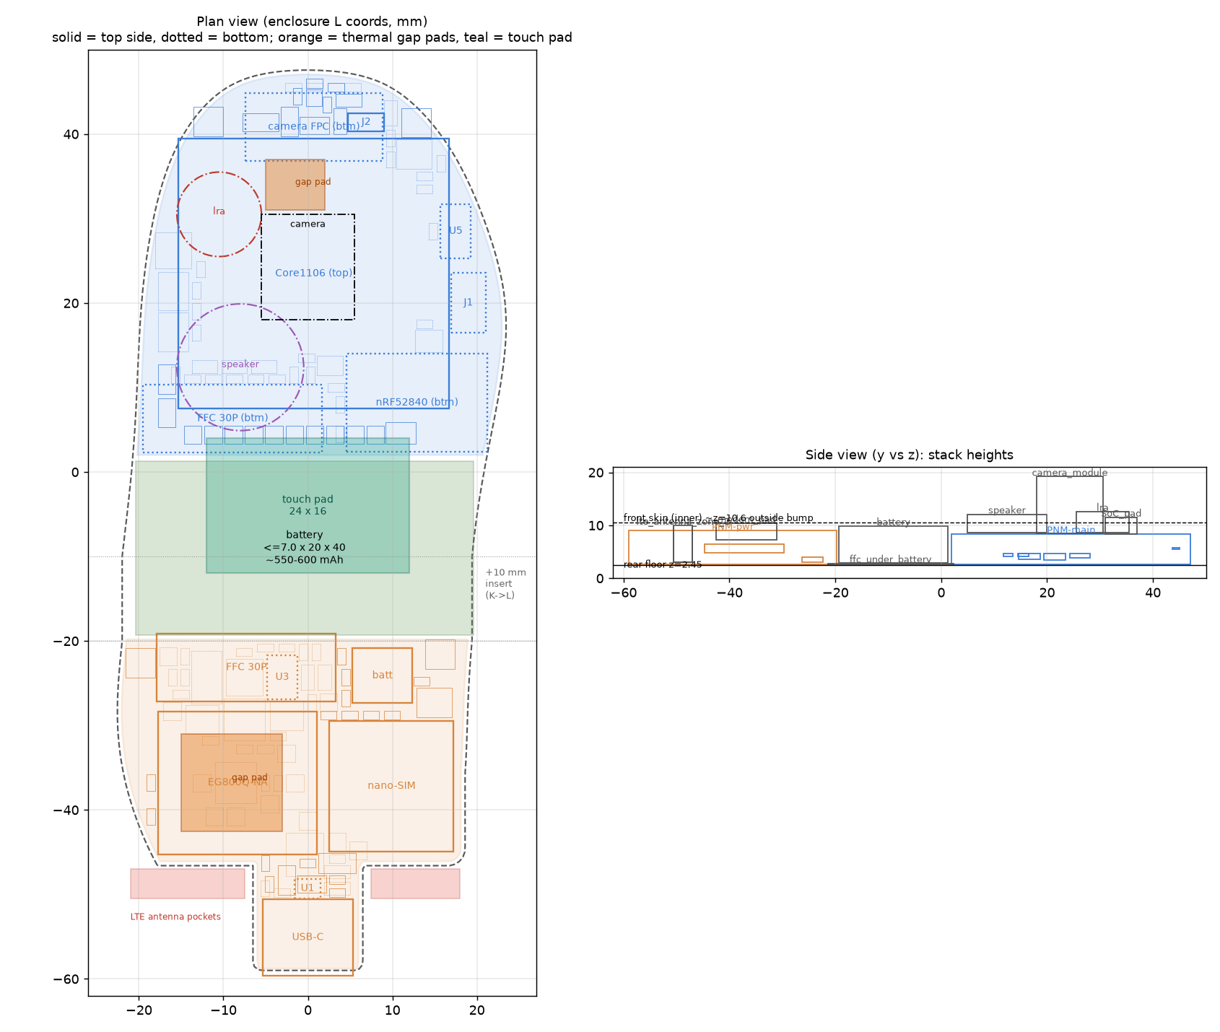
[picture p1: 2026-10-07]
hardware/kicad/out/layout-L.png

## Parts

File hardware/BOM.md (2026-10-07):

# Pneuma — Bill of Materials & Interconnect

> **Rev A is frozen, 2026-09-19: see [`REV-A.md`](REV-A.md).** It supersedes the rows below wherever they
> disagree. Modem → **EG800Q-NA**. SoC → **Luckfox Core1106-1408** module. **BM83 removed.** Camera → compact
> FPC module on the Luckfox 20P pinout. Battery → **~550–600 mAh (≤7×20×40 mm)**. Speaker → **15 mm AS01508MR-LWC40**.
> USB-C → **USB4105-GF-A**. Per-board BOMs with MPNs are generated into
> [`kicad/out/`](kicad/out) from [`kicad/tools/design.py`](kicad/tools/design.py). The enclosure grows +10 mm (enclosure L) and becomes a
> **two-piece silicone/TPU shell with no aluminum**. Rows 17–18 (unibody thermal, anodized shells) are superseded by a
> copper-foil spreader with copper-shim posts (REV-A.md §6.8).
> Everything below is kept as the research record.
>
> **Previous mechanical integration:** see [Enclosure K interface](mechanical/README.md). The current prototype uses perimeter frames and soft faces; older unibody thermal and board-stack assumptions are not validated for that construction.

Hardware for the **standalone cellular** Pneuma device: an always-on **wake-island
MCU** that powers an on-demand **Linux session SoC** + **LTE Cat-1 bis modem** +
camera. Rationale: [`../docs/ARCHITECTURE.md`](../docs/ARCHITECTURE.md) (ADR-0001,
-0006, -0007); evidence: [`../docs/RESEARCH.md`](../docs/RESEARCH.md).

> **Sourcing status (verified 2026-05).** Every line below is single-unit
> orderable by a solo maker. Prices are ~qty-1 USD, ±20%. **STEP/CAD found for 5
> of 7 enclosure-critical parts** (only the camera and a prototyping carrier need
> caliper measurement). Verify the camera FFC pin count and the exact USB-C IP
> suffix on datasheets before ordering.
>
> **Links:** Buy/CAD links go to the product page where verified, otherwise a
> Digi-Key / SnapEDA **search by part number** (always resolves the part) — confirm
> stock and the exact variant at checkout. The part numbers are the durable
> reference; URLs drift.

---

## 1. Bill of materials (buildable)

| # | Block | Orderable part | Buy at | ~$ | CAD/STEP | Notes |
|---|---|---|---|----|---|---|
| 1 | **Cellular modem** | **Quectel EG915U-EU** (Cat-1 bis, LGA-126, 23.6×19.9×2.4 mm) | [LCSC `C5248292`](https://jlcpcb.com/partdetail/Quectel-EG915UEU/C5248292) · [4gltemall](https://www.4gltemall.com/quectel-eg915u.html) | 8–12 | [SnapEDA](https://www.snapeda.com/search/?q=EG915U) | Design part; LGA = **reflow only** (see prototyping path). |
| 2 | **Session SoC** | **Rockchip RV1106G3** (256 MB — the G3 RAM matters for the TLS/audio stack) | bare: [LCSC](https://www.lcsc.com/search?q=RV1106) · dev: [Luckfox Pico Ultra](https://www.luckfox.com/EN-Luckfox-Pico-Ultra) | ~6–10 | [wiki `.step`](https://wiki.luckfox.com/Luckfox-Pico-RV1106/Downloads/) | Price = **bare chip** (the $25 Pico Ultra is a *dev* cost, not a board component). Confirmed by SoC deep pass (RESEARCH §8 / ADR-0009). Productize on a custom bare-RV1106G3 PCB. Fallback for one-chip BT: RK3566. |
| 2b | **Bluetooth-audio chip** | **Microchip BM83** (BM83SM1-00Tx, AT/source firmware) | [DigiKey](https://www.digikey.com/en/products/result?keywords=BM83SM1-00TA) · [Microchip](https://www.microchip.com/en-us/product/bm83) | ~12 | [Microchip BM83](https://www.microchip.com/en-us/product/bm83) | Owns A2DP **source** + HFP (earbud mic) + AAC via I²S + UART — offloads BT audio off the RV1106's weak BlueZ (ADR-0009). Needs its own 2.4 GHz antenna. |
| 3 | **Camera** | **SC3336 3MP Module (B)** (MIPI-CSI, F2.0) | [Waveshare](https://www.waveshare.com/sc3336-3mp-camera-b.htm) · luckfox.com | 9 | ✘ measure | Luckfox-native FFC; **confirm 15P vs 20P** against the Ultra connector. |
| 4 | **Wake-island MCU** | **Raytac MDBT50Q-1MV2** (nRF52840, 10.5×15.5×2.05 mm) | [Adafruit `4078`](https://www.adafruit.com/product/4078) · [Digi-Key](https://www.digikey.com/en/products/result?keywords=MDBT50Q-1MV2) | 6 | [SnapEDA](https://www.snapeda.com/search/?q=MDBT50Q-1MV2) | nRF52840 does the always-on KWS itself (Syntiant dropped — see gotchas). BLE for setup. |
| 5 | **Microphone** | **Infineon IM69D130V01XTSA1** (PDM, 4.0×3.0 mm) | [Digi-Key](https://www.digikey.com/en/products/result?keywords=IM69D130V01XTSA1) · breakout [Adafruit `4346`](https://www.adafruit.com/product/4346) | 2–3 | [SnapEDA](https://www.snapeda.com/search/?q=IM69D130) | Bottom-port. |
| 6 | **Audio amp** | **MAX98357A** (bare, or Adafruit `3006`) | [Adafruit `3006`](https://www.adafruit.com/product/3006) · [Digi-Key](https://www.digikey.com/en/products/result?keywords=MAX98357AETE%2BT) | 1–6 | [SnapEDA](https://www.snapeda.com/search/?q=MAX98357A) | I2S Class-D. |
| 7 | **Speaker** | **PUI Audio AS01808MR-R** (18 mm, 8 Ω, 1 W, wire leads) | [Digi-Key](https://www.digikey.com/en/products/result?keywords=AS01808MR-R) · maker: [Adafruit `3923`](https://www.adafruit.com/product/3923) / [SparkFun](https://www.sparkfun.com/mini-speaker-1w-8-ohm.html) | 2–4 | [Digi-Key](https://www.digikey.com/en/products/result?keywords=AS01808MR-R) | In stock, ships same-day. Fire upward toward the face. (Same Sky CES-20134-088PM was out of stock.) |
| 8 | **Haptic driver** | **DRV2605L** (bare, or Adafruit `2305`) | [Adafruit `2305`](https://www.adafruit.com/product/2305) · [Digi-Key](https://www.digikey.com/en/products/result?keywords=DRV2605LDGSR) | 2–8 | [SnapEDA](https://www.snapeda.com/search/?q=DRV2605L) | |
| 9 | **LRA** | **Vybronics VG1040003D** (10×3 mm, Z-axis) | [Vybronics](https://www.vybronics.com/coin-vibration-motors/lra/v-g1040003d) · [Digi-Key](https://www.digikey.com/en/products/result?keywords=VG1040003D) | 3–6 | [Vybronics drawing](https://www.vybronics.com/coin-vibration-motors/lra/v-g1040003d) | |
| 10 | **Indicator** | RGB LED (e.g. WS2812B) + optical window | [Adafruit `1938`](https://www.adafruit.com/product/1938) · [Digi-Key](https://www.digikey.com/en/products/result?keywords=WS2812B) | 0.50 | ✔ generic | Window sealed (§ENCLOSURE). |
| 11 | **PMIC / power-path** | **TI BQ24074** (bare, 1.5 A power-path) | [Digi-Key](https://www.digikey.com/en/products/result?keywords=BQ24074RGTR) · proto [Adafruit `4755`](https://www.adafruit.com/product/4755) | 2 | [SnapEDA](https://www.snapeda.com/search/?q=BQ24074) | Step up to **BQ25895** (5 A, I²C) if TX headroom demands. |
| 12 | **Battery** | **PKCell LP803860** 2000 mAh (8×36×60 mm, JST-PH) | [Adafruit `2011`](https://www.adafruit.com/product/2011) | 12.50 | datasheet drawing | Standard catalog cell (see §ENCLOSURE for the slab geometry). |
| 13 | **Waterproof USB-C** | **GCT USB4500-03-1-A** (IP67/68, mid-mount) | [Digi-Key](https://www.digikey.com/en/products/result?keywords=USB4500-03-1-A) · [GCT](https://gct.co) | 1–2 | [GCT STEP](https://gct.co) | Power **+ data**. Verified IP67 alt: GCT USB4715 ([Mouser](https://www.mouser.com/ProductDetail/GCT/USB4715-GF-A?qs=vvQtp7zwQdPhXuRDaiXpdQ%3D%3D), [STEP](https://gct.co/connector/usb4715)). |
| 14 | **Cellular antenna** | proto: **Molex 2091420180** flex (85×14.5 mm, U.FL); product: **Pulse W3796** SMD (**40×7×3 mm**, 698–2700 MHz, >65% eff.) | [flex (Digi-Key)](https://www.digikey.com/en/products/detail/molex/2091420180/10057542) · [W3796 (Digi-Key)](https://www.digikey.com/en/products/result?keywords=W3796) · pigtail [Adafruit `852`](https://www.adafruit.com/product/852) | 3–7 | [Molex 3D](https://www.molex.com/en-us/products/part-detail/2091420180) | Flex = plug-and-play U.FL for the bench. **W3796 halves the footprint on the product PCB** (full band; needs a ground-plane keepout). Tinier chips (Ignion NN03-310, 30×3 mm) want a ~100 mm ground plane → low-band drops on our 80 mm body. |
| 15 | **SIM / data** | **removable IoT SIM** — Soracom Plan01s *or* Hologram (single-unit, cuts to nano) | [Soracom](https://store.soracom.io/product/soracom-global-iot-industrial-sim/) · [Amazon 1-pack](https://us.amazon.com/dp/B01M30ZYR5) · [Hologram](https://store.hologram.io/) | ~5–6 + data | n/a | Pops into the LilyGO/Waveshare SIM slot — **this is what you order**. The **MFF2 solderable eSIM** (Soracom SGEIL01 / sysmocom, sold in packs) is a **production-PCB-only** item, not needed now. |
| 16 | **Acoustic vents** | **Gore GAW331** (IP67/68) over mic + speaker | [Gore](https://www.gore.com/products/categories/venting) (sample) | sample | n/a | MOQ/sample-gated; generic ePTFE adhesive vent for prototypes. |
| 17 | **Thermal** | aluminum unibody + graphite spreader + TIM pads (modem PA & SoC) + skin-side insulator | Digi-Key (TIM) / fab | 3–8 | — | Body *is* the heat exchanger (ADR-0006/0007). |
| 18 | **Waterproof seal** | printed **silicone gasket** (seal + RF window + LED window) | fab / cast | 1 | — | Target IP68; two anodized aluminum shells. |
| 19 | **Attachment** | magnet clamp (passive skin-side) / lanyard / clip | — | 1–3 | — | Skin-side piece stays passive + cool (Ai Pin lesson). |

### Component total (one board's worth of parts, qty 1)

The parts **are** cheap individually — they just sum across ~25 line items:

| Big-ticket items | ~$ |
|---|---|
| Battery (2000 mAh) | 12.5 |
| BM83 Bluetooth-audio | 12 |
| Cellular modem (EG915U) | 10 |
| Camera (SC3336) | 8 |
| SoC (bare RV1106G3) | 8 |
| nRF52840 module | 6 |
| LRA + speaker + thermal/graphite | ~12 |
| Everything else (mic, amp, PMIC, LED, USB-C, antenna, SIM, gasket, magnet, passives, FFC/BTB connectors) | ~35 |
| **Σ ≈** | **~$95–130 / board** |

So **the bill of *materials* is ~$110 — that part is genuinely cheap.** What makes a
*first custom board* expensive is **not the parts**; it's assembly setup + respins
(next section). Per-unit drops toward this ~$110 at volume.

### Development path (cost-optimized — don't buy a pile of breakouts)

What needs validating before a custom PCB is mostly **software/integration, not
tuning** — and it's cheap to retire on **one or two integrated dev boards**, not a
bag of breakouts. The actual *tuning* (RF, power, thermal) can't be done until the
real board + enclosure exist, so it happens *on* the PCB regardless (plan ≥2 spins).

**Recommended dev kit (~$55–65, validate → then commit the PCB):**
- **Laptop** — the Rust session app already runs here (mocks). **$0.**
- **Luckfox Pico Ultra (~$30)** — one board that *is* RV1106 + onboard audio codec +
  mic + Wi-Fi/BT + camera connector + eMMC. It replaces ~5 breakouts, and it's the
  right board to answer the **make-or-break BT-audio question** (same AIC8800-class BT
  you'd ship). *(This supersedes the earlier "skip the Ultra" note — for a
  no-breakouts plan the Ultra is the cheapest path once you count the parts it bundles.)*
- **Cellular board (~$20–28)** — [LilyGO T-A7670G R2](https://lilygo.cc) or
  [Waveshare SIM7670G HAT](https://www.waveshare.com/sim7670g-lte-cat-1-gnss-hat.htm)
  (modem + SIM slot + antenna) to bring up the realtime cellular loop.
- **IoT SIM (~$5)** + a **small speaker (~$2)**. *(optional)* **BM83 EVB** only if you
  want to prove the dedicated-chip A2DP path specifically.
- **Skip** the mic/amp/Wi-Fi/charger/LED breakouts — redundant with the Pico Ultra.

**If you own a Raspberry Pi:** use it for the cloud/architecture proof ($0; *not* the
real SoC), then treat custom-PCB spin #1 as your RV1106 bring-up — saves the Ultra,
but accepts RV1106-specific risk (its BT/ISP/power) landing first on a real board.

**Straight to a custom PCB as board-spin-1?** You *can* bench a custom board — but for
*this* stack it's a gamble, because two unknowns are painful to discover on a ~$300
board yet trivial on a $30 one:
1. **Does A2DP-to-earbuds actually work** on your chosen BT path?
2. **Does the RV1106 run app + camera + modem concurrently** under your stack?
Find those on the Pico Ultra + cellular board first; *then* lay out the PCB.

**What you genuinely can't pre-tune (so expect ≥2 PCB spins regardless):** antenna
matching + 4-radio co-existence, the RF window, power-path under modem TX bursts, and
skin-side thermals — all need the real board in the real enclosure. So you're right
that there's little *pre-PCB tuning* — but a ~$60 integration spike still saves a
wasted spin.

**Production-only (don't order now):** bare Quectel EG915U (reflow → dev board), MFF2
eSIM chip (→ removable SIM), Gore vent (MOQ → generic ePTFE for proto), Pulse W3796
antenna (dev board has its own), bare ICs (the Ultra/EVB cover them).

**Link caveats:** Digi-Key / SnapEDA links are *search-by-part-number* (always
resolve + show stock); vendor deep links may drift — the **part number is the durable
reference**. Confirm the **SC3336 FFC pin count (15P vs 20P)** and the **BM83
"AT"/source firmware** before ordering.

### Manufacturing cost reality (it's *iteration*, not parts)
**The parts are cheap (~$110 above).** What makes a *first custom board* cost real
money is the one-time assembly + respins — not the components:
- **Bare PCB fab:** 4–6 layers + controlled impedance (USB/MIPI/RF), qty ~5 → **~$30–100**.
- **Assembly (PCBA):** RV1106/EG915U/BM83 are BGA/LGA — **can't be hand-soldered**, so
  an assembly house charges stencil + setup + per-part fees → **~$100–200/run** (one-time).
- **One assembled prototype board ≈ ~$150–300** = the ~$110 of parts + a share of that
  one-time setup for a small run.
- **The scary ~$500–1,500 is the *program* cost if you respin 2–3×** (each respin
  repeats fab + assembly + setup), which the RF/power/thermal tuning usually needs.
  It's an **iteration** cost, not a parts cost.
- **"Cheap" is a volume property:** per-unit approaches the ~$110 BOM + a few $ assembly
  only at **hundreds–thousands** of units.
- **Levers:** JLCPCB/PCBWay PCBA with their **in-stock parts library** (dodges MOQ +
  bundles cheap assembly) · a modem **module** (not bare EG915U) on early spins ·
  design to the fab's standard stackup (no exotic HDI).
- **Why the dev-board step pays for itself:** a problem caught on a $30 board vs. a
  board spin is a **~10–50× difference** in money + weeks of lead time.

### Sourcing gotchas + workarounds
- **EG915U-EU is not a US radio.** Bands are EMEA (B1/3/5/7/8/20/28). There is no
  EG915U-NA; Portland / AT&T / T-Mobile need a NA SKU (e.g. EG915Q-NA / EG800Q-NA
  class, or whatever the LilyGO/Waveshare HAT actually ships). Sharing B5 is not
  coverage. Pick the regional modem before schematic.
- **EG915U is reflow-only** (LGA-126). Prototype on the LilyGO A7670 board; reflow
  the EG915U at home with a stencil + hotplate for the final build.
- **Syntiant NDP120 isn't buyable bare** (NDA/volume). Workaround: **drop it** —
  the nRF52840 alone handles always-on wake-word. (Arduino Nicla Voice carries an
  NDP120 if you ever want the ultra-low-power KWS path.)
- **eSIM has no clean single-unit** — buy a Soracom/sysmocom 10-pack, or start with
  a nano-SIM slot.
- **Gore vents aren't on distributors** — request samples, or use a generic ePTFE
  vent for prototypes.
- **No vendor STEP** for the SC3336 camera or LilyGO carrier — measure with calipers
  (both are simple rectangular boards).

### Optional capability add-ons (location, Bluetooth audio)
- **GNSS / location:** use a **GNSS-capable modem** (the prototyping SIM7670G /
  LilyGO A7670**G** already include GNSS; the bare EG915U does **not** — add a GNSS
  chip like u-blox MAX-M10 / Quectel L76) **+ a small GNSS antenna** (~7 mm GPS chip
  antenna, or a **cellular+GNSS combo flex** = one part, two U.FL leads). Enables the
  `get_location` / `directions` tools (ARCHITECTURE §8).
- **Bluetooth audio out (AirPods / BT headphones) — table-stakes (ADR-0008/0009).**
  A2DP *source* for private/clear AI voice + music. **Decided: a dedicated
  Microchip BM83** (row 2b) owns A2DP source + AAC via I²S, offloading the
  RV1106's weak BlueZ. **HFP Audio Gateway (earbud mic) is not in the BM83 AT
  Tx-mode firmware** — A2DP-out is real; two-way via AirPods mic is not, on this
  chip. See [`../docs/FEASIBILITY.md`](../docs/FEASIBILITY.md). Adds a
  **2.4 GHz BT antenna** + a pairing flow; the module itself is 32×15 mm with an
  onboard PCB antenna. (On an RK3566-class SoC you could instead use BlueZ A2DP
  directly, ~$0 — the one-chip fallback.)
- **Spotify:** software only — **librespot** (MIT, Rust) on the SoC; needs Spotify
  Premium. Music over cellular ~1 MB/min — prefer Wi-Fi.

---

## 2. Interconnect map

```
   USB-C ──VBAT/charge──▶ PMIC (power-path) ──▶ system rails ──┬─────────────────────┐
                                                              │                      │
   ┌──────────── WAKE ISLAND (nRF52840, always on) ───────────┴───┐                  │
   │  PDM mic (IM69D130) ─▶ wake-word KWS (DS-CNN/TFLM)            │                  │
   │  BUTTON ─▶ GPIO (IRQ)                                         │                  │
   │  BLE ─▶ provisioning (setup only)                            │                  │
   │  GPIO_SOC_EN ─▶ SoC power enable (load switch / PMIC EN)      │                  │
   │  UART  ◀───────────────────────────────────────────────────┐ │                  │
   └────────────────────────────────────────────────────────────┼─┘                  │
                                                                 │ control            │
   ┌──────────── SESSION BRAIN (RV1106 Linux, on-demand) ────────┴──────────────────┐ │
   │  UART  ◀─▶ wake island (wake reason, state, "done/sleep")                       │ │
   │  USB / UART(PPP) ─▶ Quectel EG915U modem ──▶ [eSIM/iSIM] ──▶ FPC antenna        │◀┘
   │  MIPI-CSI ◀─ camera sensor      GPIO_CAM_EN ─▶ camera power gate                 │
   │  I2S ─▶ MAX98357A ─▶ speaker    PDM/I2S ◀─ mic (in session)                      │
   │  I2C ─▶ DRV2605L (haptics), fuel gauge      GPIO ─▶ RGB LED                      │
   │  SPI-NAND/eMMC ─▶ OS + memory file (encrypted)                                   │
   └──────────────────────────────────────────────────────────────────────────────────┘
```

### Bus / interface summary
| Interface | Between | Purpose |
|---|---|---|
| UART | wake island ↔ SoC | wake reason, state handshake, sleep |
| GPIO (SOC_EN) | wake island → PMIC/SoC | power the session tier up/down |
| USB or UART+PPP | SoC ↔ modem | cellular data link |
| MIPI-CSI | camera → SoC ISP | on-demand JPEG |
| I2S | SoC → amp | speaker audio |
| PDM | mic → wake island (always) / SoC (session) | mic capture |
| I2C | SoC ↔ DRV2605L, fuel gauge | haptics, battery |
| BLE | wake island ↔ browser | one-time provisioning only |

### Physical interconnect: bench vs. enclosure

This device **can't be classically breadboarded** — the modem (USB), SoC↔camera
(MIPI-CSI), and antenna (RF) links break over jumper wires. Connect by bus speed:

**Bench (dev boards, not raw chips):**
- **Slow buses → Dupont jumpers** (optionally on a solderless breadboard hosting
  breakouts): I²C, UART, GPIO, power.
- **Fast/special links → native cables, never jumpers:** camera = FFC ribbon;
  modem = USB cable; antenna = U.FL coax pigtail.
- Boards: Luckfox Pico (RV1106), a Cat-1 modem carrier/HAT, nRF52840 dev kit,
  Adafruit/SparkFun breakouts (amp/mic/haptics). Optional next step: protoboard or
  a carrier PCB the modules plug into via headers.

**Enclosure (soldered, custom PCB):**
| Connector | Use |
|---|-----|
| Board-to-board (Hirose DF40 / BTB) | stack the two PCBs (slab ↔ plateau) |
| FFC/FPC flex (Molex/Hirose 0.5–1.0 mm) | camera; routing around corners |
| JST-PH / JST-SH | battery, speaker (removable) |
| U.FL / IPEX MHF | modem → FPC antenna coax |
| Pogo pins | programming/test points |

Maps to a **two-board stack**: main/battery board (slab) + SoC+modem board
(plateau), joined by one BTB connector or short flex; camera/antenna/speaker/mic/
USB-C hang off on flex/JST. USB and MIPI need impedance-controlled traces (a
KiCad PCB job, not hand wiring).

---

## 3. Power & thermal targets (validate on bench)

| State | Approx power | Notes |
|---|---|---|
| Sleep (wake island + modem registered-idle) | ~few–20 mA | SoC suspend or off; **modem stays attached** (~13 mA idle typical on EG915U). Full radio-off makes wake-to-talk too slow. |
| Active session (streaming) | ~2–4 W | modem ~0.8 A + SoC; the heat driver |
| Camera capture (brief) | + sensor power | gated off otherwise |

- Skin-facing surface must stay **≤43 °C** (target ≤40–42 °C). Strategy: on-demand
  bursts + passive graphite/Cu spreading to an outward face + skin-side insulation.
- LTE draws steadily during a session (no 2 G micro-spikes) → single LiPo + bulk
  cap + power-path PMIC; no supercap required.
- Runtime (order-of-magnitude): a 2000 mAh / 3.7 V cell is **7.4 Wh**. At the
  ~3 W session budget that is **~2.5 h of continuous talk** (2000 mAh / ~0.8 A
  LTE TX is the same answer). **All-day / multi-day only on an on-demand duty
  cycle**, and only if idle current stays in the tens of mA — which argues
  against fully powering off the modem every session. See
  [`../docs/FEASIBILITY.md`](../docs/FEASIBILITY.md).

---

## 4. Open items before schematic capture

- [ ] Confirm session SoC (Luckfox Pico Ultra / RV1106) against the realtime
      WebRTC/TLS + camera workload and its idle/boot-time power.
- [ ] Measure **wake-to-first-audio** with the modem already registered-idle vs.
      fully powered off. Full power-off is expected to be 15–40 s (see
      [`../docs/FEASIBILITY.md`](../docs/FEASIBILITY.md)) and is likely
      product-infeasible; this number decides the power architecture.
- [ ] Validate wake-island → SoC cold-boot/resume latency (affects "feel").
- [ ] Bench modem TX current + needed bulk capacitance on the chosen cell.
- [ ] Thermal mock-up: skin-side temp during a sustained session; size the
      graphite spreader; resolve antenna-vs-spreader contention for the outer face.
- [ ] Confirm SC3336 FFC pin count + GCT USB-C IP suffix on datasheets.
- [ ] eSIM (Soracom/SGP.32) provisioning + data plan.
- [ ] Secure storage for keys + memory file (SoC secure boot / encrypted flash).

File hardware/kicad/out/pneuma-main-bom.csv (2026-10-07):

Refs | Qty | Value | Manufacturer | MPN | Footprint | Description | Notes
C1 C2 C7 C8 | 4 | 22u |  |  | C_0805_2012Metric |  | 10V
C3 C10 C12 C15 C17 C24 | 6 | 100n |  |  | C_0402_1005Metric
C4 C16 C23 | 3 | 10u |  |  | C_0603_1608Metric
C5 | 1 | 1n |  |  | C_0402_1005Metric
C6 C9 C11 | 3 | 4.7u |  |  | C_0603_1608Metric
C13 C14 | 2 | 12p |  |  | C_0402_1005Metric
C18 C19 C20 C21 C22 | 5 | 1u |  |  | C_0402_1005Metric
C25 | 1 | 22n |  |  | C_0402_1005Metric |  | Cs; tune with the final electrode area
D1 | 1 | SML-LX0404SIUPGUSB | Lumex | SML-LX0404SIUPGUSB | LED_Lumex_SML-LX0404SIUPGUSB | RGB LED 1.0x1.0 mm, common anode
J1 | 1 | TC2030-NL |  |  | Tag-Connect_TC2030-IDC-NL_2x03_P1.27mm_Vertical | nRF SWD (Tag-Connect, no legs)
J2 | 1 | SPK |  |  | Pads_2x_1.2x1.6mm_P2.5mm | Speaker solder pads (wire-lead micro speaker, see BOM)
J3 | 1 | LRA |  |  | Pads_2x_1.2x1.6mm_P2.5mm | LRA solder pads (Vybronics VG1040003D)
J4 | 1 | CAMERA | Hirose | FH12-20S-0.5SH(55) | Hirose_FH12-20S-0.5SH_1x20-1MP_P0.50mm_Horizontal | Camera FPC, Luckfox 20P pinout
J5 | 1 | TO_PWR | Hirose | FH12-30S-0.5SH(55) | Hirose_FH12-30S-0.5SH_1x30-1MP_P0.50mm_Horizontal | Inter-board FFC (bottom side)
MK1 | 1 | IM69D130V01 | Infineon | IM69D130V01XTSA1 | Infineon_PG-LLGA-5-1 | PDM MEMS mic, bottom port
MK2 | 1 | IM73A135V01 | Infineon | IM73A135V01XTSA1 | Infineon_PG-LLGA-5-2 | Analog MEMS mic, bottom port
R1 | 1 | 10k |  |  | R_0402_1005Metric
R2 | 0 | 100k |  |  | R_0402_1005Metric |  | DNP
R3 R10 | 2 | 100k |  |  | R_0402_1005Metric
R4 R5 R12 R13 R15 | 5 | 4.7k |  |  | R_0402_1005Metric
R6 | 1 | 680 |  |  | R_0402_1005Metric
R7 R8 | 2 | 270 |  |  | R_0402_1005Metric
R9 | 1 | 1M |  |  | R_0402_1005Metric
R11 R14 | 2 | 100 |  |  | R_0402_1005Metric
TP1 TP2 TP3 TP4 TP5 TP6 TP7 TP8 TP9 TP10 | 10 | TestPoint |  | pad | TestPoint_Pad_D1.0mm
TP11 | 1 | TOUCH_E |  |  | SpringPad_3.0x2.0mm | Touch electrode spring contact, front face ~10 mm below the bump
U1 | 1 | Core11061408 | Luckfox | Core11061408 | Core1106-SMT-Cutout | RV1106G3 SoM, 256 MB DDR3L, 8 GB eMMC, WiFi6/BT5.2, 30x30 stamp-hole
U2 | 1 | TPS22917DBVR | TI | TPS22917DBVR | SOT-23-6 | SoC rail load switch, 2 A
U3 | 1 | MDBT50Q-1MV2 | Raytac | MDBT50Q-1MV2 | Raytac_MDBT50Q | nRF52840 module, chip antenna
U4 | 1 | MAX98357AETE+T | Analog Devices | MAX98357AETE+T | TQFN-16-1EP_3x3mm_P0.5mm_EP1.23x1.23mm | I2S class-D mono amp
U5 | 1 | DRV2605LDGSR | TI | DRV2605LDGSR | TSSOP-10_3x3mm_P0.5mm | LRA haptic driver
U6 | 1 | AT42QT1011-MAH | Microchip | AT42QT1011-MAH | DFN-8-1EP_2x2mm_P0.5mm_EP0.9x1.5mm | 1-key capacitive touch, UDFN-8 2x2
Y1 | 1 | 32.768k | ECS | ECS-.327-7-12-TR | Crystal_SMD_2012-2Pin_2.0x1.2mm | 32.768 kHz, CL 7 pF

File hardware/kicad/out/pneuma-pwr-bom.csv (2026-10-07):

Refs | Qty | Value | Manufacturer | MPN | Footprint | Description | Notes
C1 | 1 | 4.7u |  |  | C_0603_1608Metric |  | 16V
C2 C3 C4 | 3 | 10u |  |  | C_0603_1608Metric
C5 C6 C9 C15 C16 C17 C18 | 7 | 100n |  |  | C_0402_1005Metric
C7 C8 | 2 | 47u |  |  | C_0805_2012Metric |  | 6.3V
C10 C19 C20 C21 | 4 | 33p |  |  | C_0402_1005Metric
C11 | 1 | 10p |  |  | C_0402_1005Metric
C12 | 1 | 1u |  |  | C_0402_1005Metric
C13 C14 | 0 | DNP |  |  | C_0402_1005Metric |  | DNP
D1 | 1 | SMF5.0A | Littelfuse | SMF5.0A | D_SOD-123F | VBAT TVS (Quectel recommendation)
J1 | 1 | USB-C | GCT | USB4105-GF-A | USB_C_Receptacle_GCT_USB4105-xx-A_16P_TopMnt_Horizontal | USB-C receptacle, USB 2.0, top mount
J2 | 1 | BATTERY | JST | SM02B-GHS-TB | JST_GH_SM02B-GHS-TB_1x02-1MP_P1.25mm_Horizontal | 1S LiPo, polarity per Pneuma harness: pin1 = +
J3 | 1 | U.FL | Hirose | U.FL-R-SMT-1(10) | U.FL_Hirose_U.FL-R-SMT-1_Vertical | LTE antenna
J4 | 1 | nanoSIM | GCT | SIM8060-6-0-14-00-A | nanoSIM_GCT_SIM8060-6-0-14-00 | Hinged nano-SIM, no detect
J5 | 1 | TO_MAIN | Hirose | FH12-30S-0.5SH(55) | Hirose_FH12-30S-0.5SH_1x30-1MP_P0.50mm_Horizontal | Inter-board FFC (top side)
Q1 Q2 | 2 | 2N7002 | Nexperia | 2N7002 | SOT-23
R1 R2 | 2 | 5.1k |  |  | R_0402_1005Metric
R3 | 1 | 10k |  |  | R_0402_1005Metric |  | fixed 10k = 25 C; replace with pack NTC if the cell has one
R4 | 1 | 1.33k |  |  | R_0402_1005Metric |  | IIN max = 1610/1330 = 1.21 A
R5 | 1 | 3.3k |  |  | R_0402_1005Metric |  | ICHG = 890/3300 = 270 mA (~0.5C for a 550 mAh cell)
R6 R7 R8 R10 R11 R12 | 6 | 100k |  |  | R_0402_1005Metric
R9 | 1 | 150k |  |  | R_0402_1005Metric
R13 | 1 | 1k |  |  | R_0402_1005Metric
R14 R15 | 2 | 0 |  |  | R_0402_1005Metric |  | pi-match series; tune on the real antenna
R16 R17 R18 | 3 | 22 |  |  | R_0402_1005Metric
R19 | 1 | 15k |  |  | R_0402_1005Metric
TP1 TP2 TP3 TP4 TP5 TP6 TP7 TP8 TP9 TP10 TP11 TP12 | 12 | TestPoint |  | pad | TestPoint_Pad_D1.0mm
U1 | 1 | USBLC6-2P6 | ST | USBLC6-2P6 | SOT-666 | USB ESD (SOT-666, 0.6 mm)
U2 | 1 | BQ24074RGTR | TI | BQ24074RGTR | VQFN-16-1EP_3x3mm_P0.5mm_EP1.6x1.6mm | 1S Li-ion charger + power path. OUT(=VSYS) regulates to 4.4 V: modem stays on VBAT
U3 | 1 | LC709203FQH-01TWG | onsemi | LC709203FQH-01TWG | WDFN-8-1EP_4x3mm_P0.65mm_EP2.4x1.8mm | Fuel gauge (I2C 0x0B), owned by nRF
U4 | 1 | FSUSB42MUX | onsemi | FSUSB42MUX | MSOP-10_3x3mm_P0.5mm | SoC USB -> USB-C (SEL=0, default/dev) or modem (SEL=1)
U5 | 1 | EG800Q-NA | Quectel | EG800Q-NA | Quectel_EG800Q_LGA-109 | LTE Cat-1 bis, B2/4/5/12/13/66, LGA-109 15.8x17.7x2.4
U6 U7 | 2 | TXB0104RGYR | TI | TXB0104RGYR | Texas_S-PVQFN-N14 | Modem UART <-> SoC; VCCB from SoC 3V3 so it is fully off when the SoC is off
U8 | 1 | ESDA6V1-5SC6 | ST | ESDA6V1-5SC6 | SOT-23-6 | SIM ESD

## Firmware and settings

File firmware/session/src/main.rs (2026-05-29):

//! Pneuma session brain — scaffold entry point.
//!
//! Wires the mock HAL through the provider **router** (`provider::build`) into the
//! interaction state machine, and runs two demos so you can watch the full
//! Sleep → Connect → Capture → Converse → Forget loop on a laptop, no hardware:
//!   1. a Tier-1 *realtime* provider over a two-turn voice conversation + a visual query;
//!   2. a Tier-2 *composed* (STT→LLM→TTS) provider — the Claude/local path —
//!      reusing the memory the first demo saved (the only state that survives).
#![allow(dead_code)] // scaffold: the full trait/enum surface is exercised by real drivers + tests

mod config;
mod hal;
mod memory;
mod provider;
mod secure;
mod state;
mod tool;

use std::path::Path;

use config::DeviceConfig;
use hal::mock::{MockCamera, MockMic, MockModem, MockSpeaker, MockWake};
use hal::{WakeLink, WakeReason};
use memory::Memory;
use secure::MockKeyStore;
use state::Pneuma;

fn boot_memory(path: &Path) -> Memory {
    match Memory::load(path) {
        Ok(m) => {
            println!("[boot] loaded memory from {}", path.display());
            m
        }
        Err(_) => {
            println!("[boot] no memory file yet; seeding a fresh one");
            let mut m = Memory::new(memory::DEFAULT_CAP_BYTES);
            m.set("name", "Connor");
            m.set("units", "metric");
            m
        }
    }
}

fn run_demo(
    title: &str,
    config: DeviceConfig,
    mic: MockMic,
    wakes: Vec<WakeReason>,
    mem_path: &Path,
) -> Result<(), Box<dyn std::error::Error>> {
    println!("\n========== {title} ==========");

    // The router picks the driver from config and pulls the key from secure storage.
    let keys = MockKeyStore;
    let provider = provider::build(&config, &keys)?;

    let memory = boot_memory(mem_path);
    let mut device = Pneuma::new(
        Box::new(mic),
        Box::new(MockSpeaker),
        Box::new(MockCamera),
        Box::new(MockModem::offline()),
        provider,
        memory,
        mem_path.to_path_buf(),
        config,
    );

    // The wake island would feed these wake events; here they're simulated.
    let mut wake = MockWake::with(wakes);
    while let Some(reason) = wake.next_wake() {
        println!("\n--- wake: {reason:?} ---");
        device.run_once(reason)?;
        wake.power_down();
    }
    println!("\nmemory now:\n{}", device.memory().serialize());
    Ok(())
}

fn main() -> Result<(), Box<dyn std::error::Error>> {
    println!("=== Pneuma session brain (scaffold: mock HAL + provider router) ===");
    let mem_path = std::env::temp_dir().join("pneuma_memory.toml");

    // Demo 1 — Tier-1 realtime: a two-turn voice conversation, then a visual query.
    run_demo(
        "Tier-1 realtime (mock)",
        DeviceConfig {
            provider: "mock".into(),
            model: "mock-realtime".into(),
            key_ref: "secure://none".into(),
        },
        MockMic::conversation(2, 1),
        vec![WakeReason::WakeWord, WakeReason::Visual],
        &mem_path,
    )?;

    // Demo 2 — Tier-2 composed (STT→LLM→TTS), the Claude/local path. Loads the
    // memory demo 1 saved, proving persistence across the only surviving state.
    run_demo(
        "Tier-2 composed (mock)",
        DeviceConfig {
            provider: "mock-composed".into(),
            model: "claude-ish".into(),
            key_ref: "secure://none".into(),
        },
        MockMic::conversation(1, 0),
        vec![WakeReason::Visual],
        &mem_path,
    )?;

    Ok(())
}

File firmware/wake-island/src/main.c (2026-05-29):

/*
 * Pneuma wake-island firmware (nRF52840, Zephyr / nRF Connect SDK).
 *
 * Always-on co-processor: listen for the wake word / button, power up the Linux
 * session SoC on demand, hand off over UART, then power it back down. This is
 * what keeps the power- and heat-hungry tier off ~99% of the time
 * (see docs/ARCHITECTURE.md §1 and docs/PROTOCOL.md).
 *
 * STATUS: scaffold. Builds against the nRF Connect SDK toolchain (not part of
 * this repo's CI). Module bodies are stubs marked TODO.
 */
#include <zephyr/kernel.h>

#include "pneuma.h"
#include "wakeword.h"
#include "button.h"
#include "power.h"
#include "uart_link.h"

int main(void)
{
	wakeword_init();
	button_init();
	power_init();
	uart_link_init();

	for (;;) {
		enum wake_reason reason = WAKE_NONE;

		if (wakeword_detected()) {
			reason = WAKE_WORD;
		} else {
			button_event(&reason); /* sets reason if a button fired */
		}

		if (reason != WAKE_NONE) {
			power_soc_on();              /* assert SOC_EN -> boot session tier */
			uart_link_send_wake(reason); /* tell the SoC why we woke */
			uart_link_wait_for_sleep();  /* block until the SoC says SLEEP */
			power_soc_off();             /* cut the session tier */
		}

		/* TODO: replace polling with IRQ/event-driven low-power idle so the
		 * island truly sips µA between wakes. */
		k_msleep(10);
	}

	return 0;
}

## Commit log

2026-05-28 Add founding architecture and research docs
    Establish Pneuma as a screenless, voice-first wearable AI device with
    on-demand vision and a pluggable ('bring your own LLM') model.
    - README: project vision, three-tier system, hardware target, layout
    - docs/ARCHITECTURE: pendant/app/provider split, two-tier provider
    abstraction (Realtime + Composed), v1 single-ESP32-S3 platform,
    wake word, screenless UX, privacy posture, and ADRs 0001-0003
    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
2026-05-28 Lock electronics core: single nRF5340 + SPI camera
    Reopen and supersede ADR-0001 after a second research pass. The device is
    a brain-offloaded I/O node, so optimize for idle power, not on-board
    compute:
    - ESP32-S3 can't run wake word from deep sleep (~25-40mA always-listening)
    vs nRF ~3-8mA -> 5-8x power gap; ~33-67h on 250mAh. Rules out single S3.
    - Single nRF5340 + ArduCAM Mega SPI camera is viable and smallest: Nordic
    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
2026-05-28 Design the companion app + BLE protocol contract
    Define what the app is: the brain-router where 'bring your own LLM'
    lives. The pendant has no internet and knows no models; the app holds
    credentials, routes providers, and bridges BLE.
    - docs/APP.md: responsibilities (keyvault, provider router, BLE bridge,
    session engine, UX), internal split (Flutter shell + pure-Dart
    pneuma-core), provider driver interface, direct-to-provider topology
    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
2026-05-29 Pivot to standalone cellular, app-less, ephemeral device
    Major architecture change following two clarifications: the device must
    work standalone WITHOUT a phone, and there is NO app — the device is
    ephemeral except for one small internal memory file.
    Standalone + cellular + realtime voice forces a small Linux SoC (not an
    MCU): research shows ESP32-over-cellular realtime AI is unproven and the
    robust path is a Linux SoC + Cat-1 bis modem (the Humane Ai Pin pattern).
    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
2026-05-29 Add enclosure co-design: aluminum heat-exchanger body, IP68, RF window
    Capture the mechanical design direction:
    - Aluminum unibody as the heat exchanger (iPhone 17 Pro-style): strap the
    two heat sources (modem PA + SoC) to it via TIM + graphite; on-demand
    bursts soak into the metal mass without spiking. Radiate from the
    outward face, insulate the skin side (<=43C).
    - Waterproof (IP68): printed silicone gasket, Gore/Saati acoustic
    membranes for mic/speaker, and portless charging (Qi or pogo, no USB-C).
    - Central RF tension resolved: a metal body is a Faraday cage, so the
    cellular antenna needs a non-conductive RF window isolated from the
    aluminum, edge-placed away from the body (v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
2026-05-29 Set target enclosure envelope to ~40x80x20 mm
    The ~64 cm3 target is roomy (well above the parts' floor): fits a
    ~2000-2500 mAh battery (~10h+ talk, multi-day on-demand) and ~112 cm2 of
    surface + aluminum mass for comfortable thermal headroom. Flag: 20 mm is
    chunky against the chest -- build the first mock-up at full thickness,
    diet toward ~10-14 mm later by shrinking the battery.
    Update ENCLOSURE size section + BOM battery row.
    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
2026-05-29 Adopt iPhone-Air-style form: thin battery slab + component plateau
    - Two-zone enclosure: thin slab (battery + PCB, ~8-10 mm, skin side) +
    an outward aluminum plateau housing camera/SoC/modem/speaker (~14-18 mm).
    - Battery is the slab: ~5-7 x 36 x 72 mm LiPo -> ~2000-2500 mAh.
    - Thermal win: hot parts (modem PA + SoC) live in the outward plateau, so
    it radiates away from the body while the cool battery slab faces skin --
    resolves radiator-vs-skin tension by geometry.
    - Charging: lean magnetic pogo-pin (Qi won't pass the aluminum body).
    Update ENCLOSURE (form factor, thermal, charging) + BOM (battery, charging).
    https://claude.ai/code/session_0147zfyYUbBv7uga9e5q98Dt
2026-05-29 Switch to waterproof USB-C, gasket-as-RF-window, attachment + LED window
    - Charging: USB-C (sealed IP68-style) instead of Qi/pogo -- avoids the
    aluminum Faraday issue and restores a data path (flashing, dev/debug,
    OTA recovery). Port is the one waterproofing weak point; solved with a
    gasketed receptacle + gasket wrapping the opening.
    - Antenna: a real slot/aperture in the aluminum filled by the RF-transparent
    silicone gasket = seal + RF window in one part. Flag: tune with the metal
    aperture present.
    - Enclosure: two anodized aluminum shells + compressed silicone gasket;
    optical LED window; thermal-break caveat (gasket isolates the shells --
    accept plateau-only radiation, or bri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
2026-05-29 Scaffold firmware: Rust session brain (runnable) + C wake-island stubs
    Session brain (firmware/session, Rust, std-only so it builds + runs on a
    laptop with no hardware/network):
    - Provider abstraction as real traits: Provider/Session, Tier 1 Realtime vs
    Tier 2 Composed (docs/ARCHITECTURE.md S3). Mock provider drives the loop;
    OpenAI gpt-realtime driver stubbed with its implementation plan.
    - HAL traits (AudioIn/AudioOut/Camera/Modem/WakeLink) + mock impls.
    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
2026-05-29 Make BOM buildable with verified parts + CAD; silence scaffold warnings
    BOM: replace indicative parts with single-unit-orderable, maker-sourced
    parts (verified 2026-05), each with buy link, ~price, and CAD/STEP status:
    - SoC: Luckfox Pico Ultra (RV1106, has STEP); modem: Quectel EG915U
    (SnapEDA STEP, reflow-only) with LilyGO A7670 as the no-reflow prototyping
    path; camera SC3336; wake MCU Raytac MDBT50Q-1MV2 (nRF52840 does KWS
    itself -- Syntiant NDP120 dropped, not maker-buyable bare).
    - Mic IM69D130, amp MAX98357A, speaker CES-20134, haptics DRV2605L+Vybronics
    LRA, charger BQ24074, battery PKCell LP803860 2000mAh (8x36x60),
    waterproof USB-C GCT USB4500, Taoglas FXUB63 antenna, Sor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
    [main.rs]
2026-05-29 Document physical interconnect: bench dev boards + final two-board stack
    - BOM: add 'Physical interconnect: bench vs. enclosure' -- this device
    can't be classically breadboarded (modem/USB, camera/MIPI, antenna/RF
    break over jumpers). Bench = dev boards + Dupont (slow buses) + native
    cables (camera FFC, modem USB, antenna U.FL). Enclosure = soldered
    custom PCB with BTB / FPC flex / JST / U.FL connectors.
    - ENCLOSURE: note the slab+plateau maps to a two-board stack joined by a
    board-to-board connector or flex.
    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
2026-05-29 session: add Tier-2 composed provider, router, key store, multi-turn
    Build out the session brain's core architecture (still dependency-free,
    laptop-runnable):
    - provider/composed.rs: Tier-2 Composed provider (STT -> text LLM -> TTS)
    with Stt/Llm/Tts stage traits and a mock implementation -- the path for
    models with no native speech-to-speech (Claude) and future local models.
    Keeps an ephemeral in-session history for LLM context; never persisted.
    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
2026-05-29 session: add tool-calling (MCP-style) round-trip
    The model can now ask the device to run a tool mid-turn; the device
    executes it and hands the result back, and the model continues with it.
    - tool.rs: Tool trait + ToolRegistry + a built-in get_time demo tool;
    errors (incl. unknown tool) return as JSON, never panic.
    - Session::push_tool_result (default no-op) closes the call->run->result
    ->continue loop; the mock realtime session demonstrates a real round-trip.
    - state machine dispatches ToolCall events through the registry inside the
    converse loop.
    8 tests pass; cargo run shows get_time invoked and its result folded into
    the reply.
    https://claude.ai/code/session_0147zfyYUbBv7uga9e5q9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
    [main.rs]
2026-05-29 BOM: add clickable buy + CAD links to every line item
    The parts/sources were named but not linked. Hyperlink each row using
    verified URLs (product pages where confirmed, else Digi-Key/SnapEDA
    search-by-part-number which always resolves), keeping the existing part
    choices. Add a verified IP67 USB-C alternative (GCT USB4715) and link the
    cellular prototyping boards (LilyGO A7670 / Waveshare SIM7670G HAT) and
    the EG915U SnapEDA footprint. Note that part numbers are the durable
    reference and URLs may drift.
    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
2026-05-29 BOM: swap out-of-stock speaker for in-stock PUI Audio AS01808MR-R
    Same Sky CES-20134-088PM is out of stock. Replace with PUI Audio
    AS01808MR-R (18 mm, 8 ohm, 1 W, wire leads, Digi-Key same-day), keeping
    Adafruit 3923 / SparkFun as maker-stock alternates.
    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
2026-05-29 enclosure: add opening/cutout sizes; flag oversized antenna
    - New 'Enclosure openings' section: design-start cutout sizes for USB-C,
    camera, antenna RF window, LED, mic, speaker, button, with sealing method
    per opening (verify against each part's datasheet panel cutout).
    - Flag that the BOM antenna (Taoglas FXUB63, ~96x21mm) is larger than the
    80mm body -> pick a ~40x10mm-class LTE FPC and size the RF window to it.
    - Refresh stale open items: charging is sealed USB-C (not Qi/pogo).
    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
2026-05-29 Source fitting antenna (Molex 2091420180); note Luckfox board size
    - Antenna: replace oversized Taoglas FXUB63 (~96x21mm) with Molex
    2091420180 (698-4000MHz flex, 85x14.5x0.1mm, U.FL, adhesive, Digi-Key
    in stock, Molex 3D+spec). Correct the earlier ~40x10mm guidance: LTE
    700MHz low band needs length, so ~85mm is the floor for full-band; it
    fits the 80mm body by bending the flex up the end wall. Going smaller
    trades away the low band.
    - Note the Luckfox Pico Ultra is a 50x50mm bench board with full RJ45 +
    USB-A (dev-only, omit for the wearable); productize on a bare-RV1106 PCB.
    - Update ENCLOSURE antenna section, openings row, and open items.
    https://claude.ai/code/session_0147zf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
2026-05-29 Clarify bench-board spend and antenna options
    - Prototyping path: you don't need the $25 Pico Ultra. Develop the brain
    on the laptop (already runs); validate real camera/modem/audio I/O on a
    Raspberry Pi you may own or the ~$8 base Luckfox Pico; reserve RV1106
    for the custom PCB.
    - Antenna: frame the Molex flex as the PROTOTYPE choice, and document the
    product-grade options small wearables actually use -- LDS (laser-direct-
    structured, the smartwatch standard) and metal-frame/slot antennas (worth
    exploring since we already have an aluminum body). Start flex, move to
    LDS/frame at enclosure tuning.
    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
2026-05-29 Add Ai Pin teardown reference; calibrate frame-antenna difficulty
    - RESEARCH.md §7: Humane Ai Pin teardown notes from the board photos
    (Snapdragon SM7125 + Kingston eMCP + discrete Qualcomm SDR675/PM6350/
    Skyworks RF chain; multi-board + connector construction; LDS/chassis
    antenna inferred). Lessons reinforce: a module collapses the RF chain,
    cloud+on-demand beats their heavy-local-compute thermal failure.
    - ENCLOSURE §3: replace the vague 'frame later' line with an honest
    easiest->hardest antenna ladder. Frame/slot antenna is the hardest
    (sim + chamber + frozen mechanics + RF engineer); recommend shipping on
    flex and hiring out a ground-coupled chip or LDS for the integrated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
2026-05-29 Antenna: add smaller Pulse W3796 (40x7mm) as the product-PCB option
    Found a genuinely smaller full-band option: Pulse W3796 SMD, 40x7x3mm,
    698-2700MHz, >65% efficiency -- ~half the flex footprint while keeping
    700MHz low band. Plan: prototype on the 85mm U.FL flex (plug-and-play),
    ship the W3796 on the product PCB (needs a ground-plane keepout) ->
    smaller ~45x12mm RF window = more aluminum for the heat spreader.
    Correct the earlier 'small = lose low-band' overstatement: that only
    holds for tiny ground-plane-booster chips (e.g. Ignion NN03-310, 30x3mm)
    that want a ~100mm ground plane and compromise low-band on our 80mm body.
    Update BOM antenna row, ENCLOSURE size discussion, openings row, o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
2026-05-29 Add location/media capabilities + power modes (nav, Spotify, BT audio)
    - firmware: add get_location, directions, play_music tools to the
    registry (mocked, deterministic) + tests -- proves the device can do
    location/nav and media via the existing tool layer (8 tests pass).
    - ARCHITECTURE §8: 'Capabilities & power modes' -- sleep / on-demand Q&A
    / navigation / media, with realistic power per mode. Navigation is cheap
    (route cached, wake-island tracks GPS, SoC wakes per turn); music over
    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
2026-05-29 Promote Bluetooth audio to a first-class feature (ADR-0008)
    - ADR-0008: Bluetooth A2DP audio out is table-stakes alongside the
    speaker. Path A (preferred): require BlueZ A2DP-source support as a hard
    SoC/module selection criterion (mature on Linux; RV1106 IPC BSP is the
    risk). Path B (fallback): dedicated A2DP-source chip fed by I2S. Adds a
    2.4GHz BT antenna + pairing; routes through a second AudioOut HAL impl;
    optional HFP for the earbud mic.
    - Fix stale ADR-0007: charging is sealed USB-C (data path), not portless
    Qi/pogo -- aligns the ADR with the BOM/ENCLOSURE decision.
    - Update ARCHITECTURE audio-out row + capabilities bullet; promote the BOM
    Bluetooth entry from 'optional/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
2026-06-01 SoC deep pass: commit RV1106 G3 + Microchip BM83 (ADR-0009)
    Five-angle sourced research resolved the pivotal SoC decision:
    - #1 realtime audio: a single A7 is enough (Opus-over-WebSocket is light;
    camera JPEG/H.264 offloads to the RV1106 ISP+VPU). Quad-A55 only needed
    for software video encode / full peer WebRTC.
    - #3 camera ISP: RV1106 has it; among general SoCs only RK3566 matches.
    - #2 BT A2DP (deciding factor): RV1106's BlueZ is broken/BLE-flavored ->
    A2DP-to-earbuds unproven. Fix = dedicated Microchip BM83 (A2DP source +
    HFP + AAC over I2S, ~2), offloading BT audio off the SoC.
    Verdict: keep the tiny/low-power RV1106 G3 + add BM83 (honors the
    smallest/lowest-power lean). RK3566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
2026-06-01 BOM: fix eSIM row + add pre-order checklist (buy-now vs production-only)
    - eSIM was misleading: the MFF2 solderable chip (Soracom SGEIL01/sysmocom)
    is pack-sold/production-only. Replace row 15 with the removable IoT SIM
    you actually order now -- Soracom Plan01s / Hologram, verified
    single-unit (store/Amazon/DigiKey), cuts to nano for the dev board slot.
    - Add an 'Order checklist' to the prototyping path: explicit buy-now bench
    list vs do-not-order-yet (bare EG915U, MFF2 eSIM, Gore vent, W3796 SMD,
    bare ICs), plus link caveats (search-by-PN links, confirm SC3336 FFC pin
    count + BM83 AT/source firmware).
    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
2026-06-01 BOM: cost-optimize the dev path (integrated dev kit, not a breakout pile)
    Reframe development around minimal spend: ~5-65 dev kit (laptop +
    Luckfox Pico Ultra, which bundles SoC+audio+mic+WiFi/BT+camera and is the
    right board to test the BT-audio question, + a cellular board + SIM +
    speaker) instead of a bag of breakouts. Supersede the earlier 'skip the
    Ultra' note -- for a no-breakouts plan the Ultra is cheapest once you
    count what it bundles.
    Answer 'straight to custom PCB?' honestly: the two unknowns worth a 0
    dev pass (A2DP-to-earbuds works; RV1106 runs app+camera+modem together)
    are painful to discover on a ~00 board. But the user is right that
    little PRE-PCB tuning exists -- RF/power/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
2026-06-02 BOM: add manufacturing cost reality note (per-attempt vs volume)
    Document why a first custom board isn't cheap: bare PCB (~$30-100) is not
    the cost driver -- components (~$90-130/board + MOQ overbuy) and PCBA
    assembly (~$100-200/run, BGA/LGA can't be hand-soldered) are. A working
    board realistically takes ~$500-1,500 across 2-3 spins; per-unit only
    approaches the BOM cost at volume. Includes cost levers (JLCPCB/PCBWay
    in-stock parts, modem module early, standard stackup) and the ~10-50x
    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
2026-06-02 BOM: separate parts cost (~$110) from iteration cost; add component total
    Clear up the conflation that made parts look expensive:
    - Add a 'Component total' table: ~$95-130/board across ~25 line items
    (big-ticket: battery, BM83, modem, camera, SoC, nRF). The parts ARE cheap.
    - Fix the SoC row price to the BARE chip (~$6-10); the $25 Pico Ultra is a
    dev cost, not a board component (was inflating the apparent parts cost).
    - Reframe the manufacturing note: parts ~$110; one assembled prototype
    ~$150-300; the ~$500-1,500 is the program cost only if you respin 2-3x
    -- an iteration cost, not a parts cost.
    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
2026-09-01 Add an independent feasibility review of the standalone spec
    The current ADRs describe a consumer cellular wearable; the BOM costs a
    desk prototype. Document where physics and datasheets support the idea
    (on-demand bursts, Cat-1 for voice, cloud brain) and where v1 as written
    does not (wake-to-audio if the modem is cold, ~2.5 h not 10 h of talk,
    EG915U-EU bands vs US, BM83 AT firmware has no HFP AG).
    Correct the BOM runtime claim and flag the EU-only modem and BM83 HFP
    gap so they are not copied into a schematic.
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2026-09-20 Freeze Rev A: two-board design, placed PCBs, enclosure L interface
    Rev A is a module-based design in two boards joined by a 30-way FFC that runs
    under the battery: PNM-MAIN (Luckfox Core1106-1408 + nRF52840 wake island +
    audio + camera FPC) and PNM-PWR (USB-C, BQ24074, EG800Q-NA, nano-SIM, fuel
    gauge, USB mux, touch).
    Everything generates from hardware/kicad/tools/design.py, so the schematic, the
    PCB, the BOM and the enclosure interface cannot drift apart; tools/build.sh
    rebuilds the lot and a fresh clone was verified to rebuild clean. Schematics
    pass ERC with 0 errors, the placed PCBs pass DRC with 0 violations (routing is
    still to do), and a solid-intersection check of the boards, batter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
    [audio.kicad_sch, compute.kicad_sch, interconnect.kicad_sch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]
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2026-09-20 Move the touch pad under the camera bump, per the intended interaction
    The touch area was over the battery, following K's "thin touch area" on the
    lower front face. It should sit ~10 mm below the camera bump, where a finger
    lands: a 24 x 16 mm electrode at x -12..12, y -12..4 on the front membrane.
    Consequences carried through:
    - the AT42QT1011 front-end moves from PNM-PWR to PNM-MAIN beside the nRF, so
    the electrode run is short and TOUCH_OUT no longer crosses the FFC. FFC pin
    27 becomes GND
    - the electrode contacts PNM-MAIN TP11 at (11.0, 4.6)
    - the speaker moves +2.2 mm in y to clear the pad. It stays the 1 W 15 mm
    round part: the only sub-15 mm options are 5 mW earpiece receive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
    [interconnect.kicad_sch, pneuma-main-bom.csv, pneuma-main.kicad_pcb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]
2026-09-21 Drop the copper spreader: run the numbers, use two gap pads
    The copper-foil + shim-post + putty stack was fiddly and, worse, depended on a
    rigid post holding pressure against a silicone wall that cannot hold tolerance.
    tools/thermal_estimate.py (lumped, first order) says it was not needed:
    - skin area 186 cm2 -> 5.4 K/W, so 43 C skin arrives at ~3.3 W CONTINUOUS no
    matter what is inside. The ceiling is surface area, not conduction
    - a 60 s session at 3 W lifts the whole device ~2.3 K (time constant ~6 min)
    - the modem's local step across a bare 1.5 mm air gap is +8 K at 60 s but
    +36 K at 10 min; ONE silicone gap pad takes that to +0.5 K
    So: the PCB does the spreading (4-layer copper i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
    [pneuma-main.kicad_pcb, pneuma-pwr.kicad_pcb]

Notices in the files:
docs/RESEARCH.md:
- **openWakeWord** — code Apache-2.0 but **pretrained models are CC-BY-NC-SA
